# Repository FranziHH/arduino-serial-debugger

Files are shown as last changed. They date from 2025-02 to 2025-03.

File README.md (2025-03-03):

# ! Fork From arduino-serial-debugger
This is Forked From https://github.com/ma-ha/arduino-serial-debugger

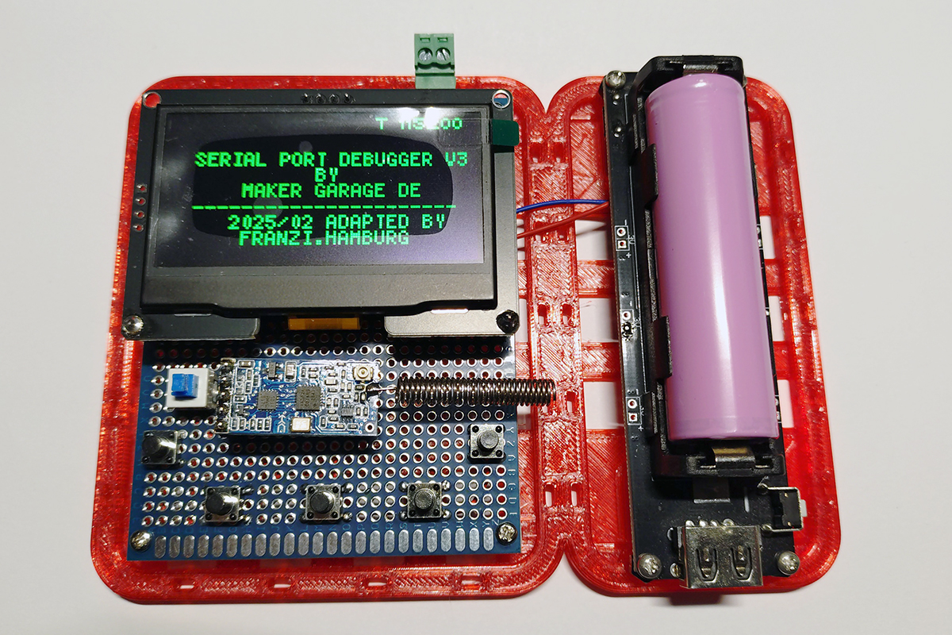
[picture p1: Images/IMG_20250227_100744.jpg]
Final Device with 18650 Battery
 
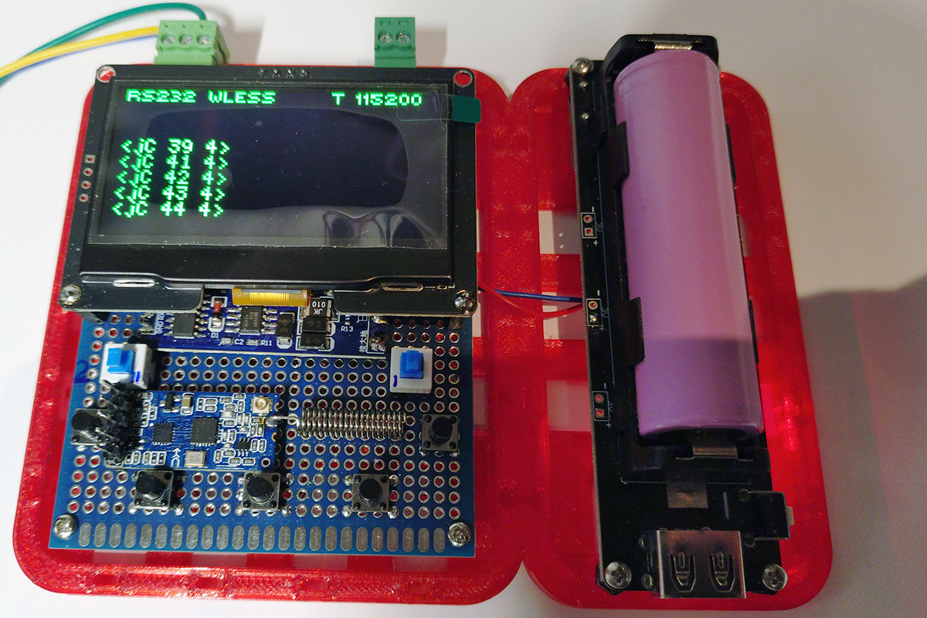
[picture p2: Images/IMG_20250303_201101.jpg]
Final Device Input HC12 wireless
 
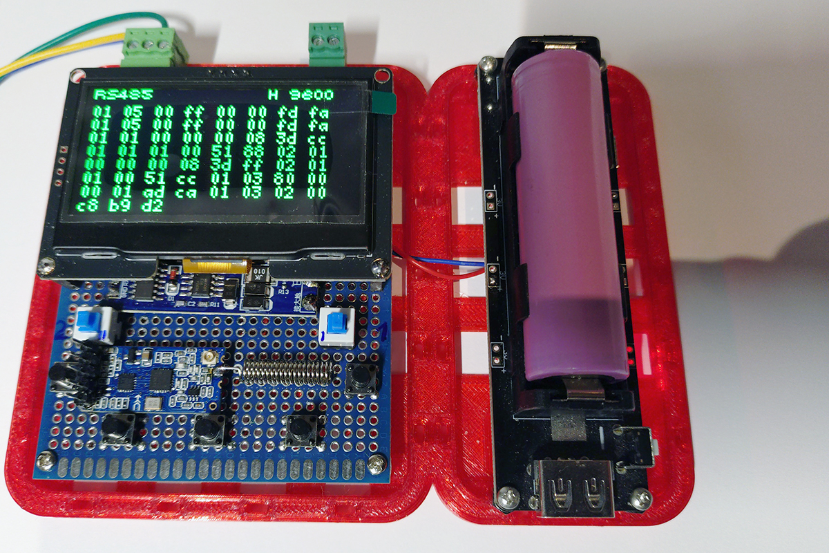
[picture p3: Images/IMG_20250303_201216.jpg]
Final Device Input RS485
 

# arduino-serial-debugger

Wire a Arduino Micro with a I2C OLED and 2 buttons, put it in a case 
... and you have a "Serial Port Debugger".

Push Buttons:
1. Toggle BAUD rate
2. Toggle display mode: HEX, BIN or TEXT

I've made a YouTube video about this project (German):
https://youtu.be/XUHYciV1GeM

# New
- Boards Arduino Nano and Uno added: Here debugging is disabled, there is only a hardware serial interface
- The display definition has been moved to config.h. Individual settings are possible here.

# Changes
- for easier use converted to vsCode
- third Button: Clear Screen added
- Added code for use with ESP32
- Error: interfaces must not be accessed in the interrupt
- ToDo: It is possible to add other boards for use

### ESP32-WROOM-32D

[ESP32 Pinout Reference](https://lastminuteengineers.com/esp32-pinout-reference/)
<br>

##### Connections
I2C Display, e.g.: 2,4-Zoll-OLED-Display 128x64 I2C SSD1309
- SCL - GPIO22
- SDA - GPIO21

Buttons - one PIN to GND
- Button Baud - GPIO19
- Button Mode - GPIO14
- Button Cls  - GPIO18

Serial Port (2)
- TX2 - GPIO17 (unused)
- RX2 - GPIO16
<br>

##### Additional
In addition, an HC-12 module was integrated
to monitor the wireless transmission
<br>

##### Images
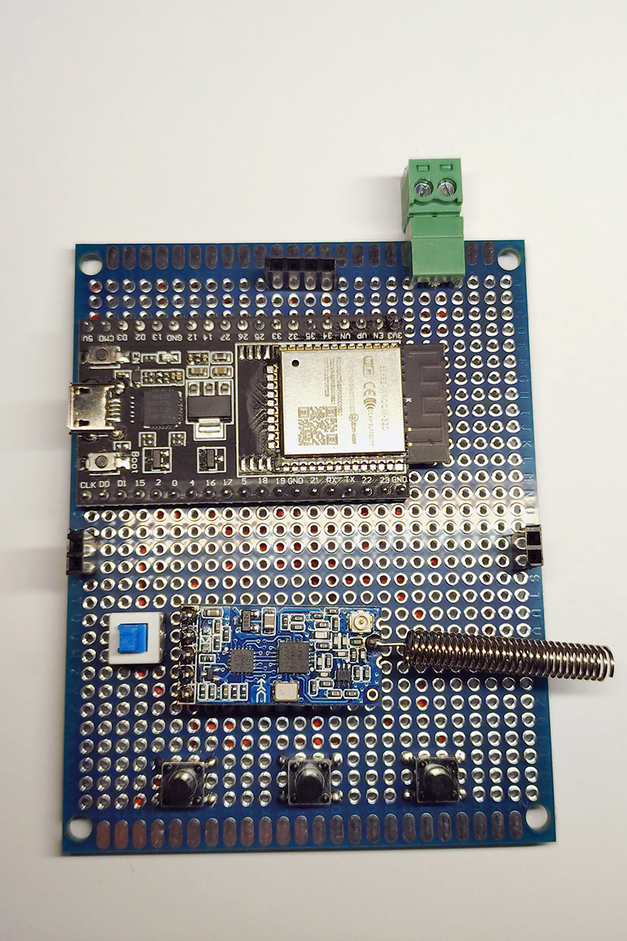
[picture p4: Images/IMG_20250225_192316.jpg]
PCB with ESP32
   
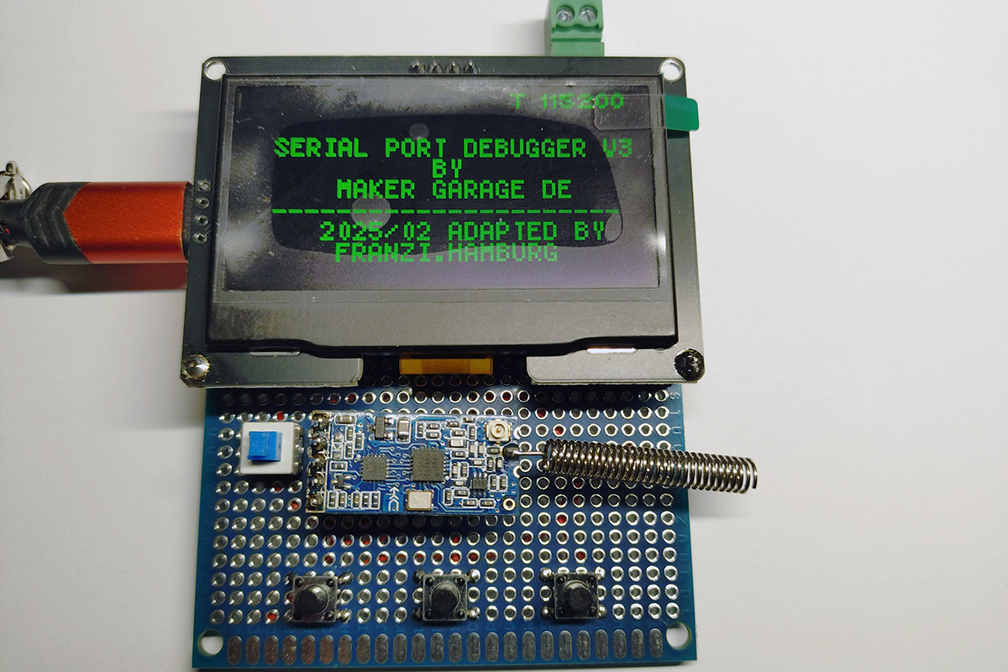
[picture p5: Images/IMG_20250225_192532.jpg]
Boot Screen
   
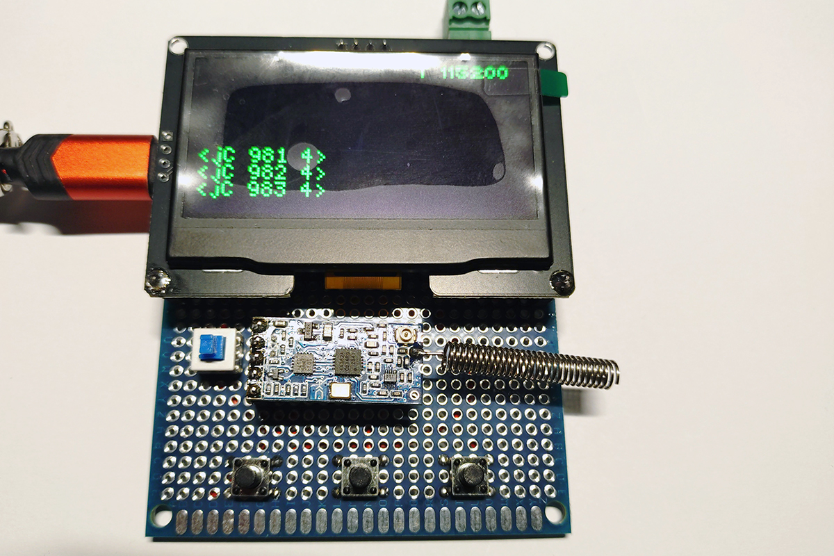
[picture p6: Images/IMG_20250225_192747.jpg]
Monitoring


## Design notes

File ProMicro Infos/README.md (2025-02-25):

# Upload ProMicro failes

https://learn.sparkfun.com/tutorials/pro-micro--fio-v3-hookup-guide/troubleshooting-and-faq

You need an Reset Button and must be fast ...

https://web.archive.org/web/20240706045800/https://forum.sparkfun.com/viewtopic.php?f=96&t=53770

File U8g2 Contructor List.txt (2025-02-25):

// Please UNCOMMENT one of the contructor lines below
// U8g2 Contructor List (Frame Buffer)
// The complete list is available here: https://github.com/olikraus/u8g2/wiki/u8g2setupcpp
// Please update the pin numbers according to your setup. Use U8X8_PIN_NONE if the reset pin is not connected
//U8G2_NULL u8g2(U8G2_R0);	// null device, a 8x8 pixel display which does nothing
//U8G2_SSD1306_128X64_NONAME_F_4W_SW_SPI u8g2(U8G2_R0, /* clock=*/ 13, /* data=*/ 11, /* cs=*/ 10, /* dc=*/ 9, /* reset=*/ 8);
//U8G2_SSD1306_128X64_NONAME_F_4W_HW_SPI u8g2(U8G2_R0, /* cs=*/ 12, /* dc=*/ 4, /* reset=*/ 6);	// Arduboy (Production, Kickstarter Edition)
//U8G2_SSD1306_128X64_NONAME_F_4W_HW_SPI u8g2(U8G2_R0, /* cs=*/ 10, /* dc=*/ 9, /* reset=*/ 8);
//U8G2_SSD1306_128X64_NONAME_F_3W_SW_SPI u8g2(U8G2_R0, /* clock=*/ 13, /* data=*/ 11, /* cs=*/ 10, /* reset=*/ 8);
//U8G2_SSD1306_128X64_NONAME_F_3W_HW_SPI u8g2(U8G2_R0, /* cs=*/ 10, /* reset=*/ 8);
//U8G2_SSD1306_128X64_NONAME_F_HW_I2C u8g2(U8G2_R0, /* reset=*/ U8X8_PIN_NONE);
//U8G2_SSD1306_128X64_ALT0_F_HW_I2C u8g2(U8G2_R0, /* reset=*/ U8X8_PIN_NONE);   // same as the NONAME variant, but may solve the "every 2nd line skipped" problem
//U8G2_SSD1306_128X64_NONAME_F_SW_I2C u8g2(U8G2_R0, /* clock=*/ 13, /* data=*/ 11, /* reset=*/ 8);
//U8G2_SSD1306_128X64_NONAME_F_SW_I2C u8g2(U8G2_R0, /* clock=*/ SCL, /* data=*/ SDA, /* reset=*/ U8X8_PIN_NONE);   // All Boards without Reset of the Display
//U8G2_SSD1306_128X64_NONAME_F_SW_I2C u8g2(U8G2_R0, /* clock=*/ 16, /* data=*/ 17, /* reset=*/ U8X8_PIN_NONE);   // ESP32 Thing, pure SW emulated I2C
//U8G2_SSD1306_128X64_NONAME_F_HW_I2C u8g2(U8G2_R0, /* reset=*/ U8X8_PIN_NONE, /* clock=*/ 16, /* data=*/ 17);   // ESP32 Thing, HW I2C with pin remapping
//U8G2_SSD1306_128X64_NONAME_F_6800 u8g2(U8G2_R0, 13, 11, 2, 3, 4, 5, 6, A4, /*enable=*/ 7, /*cs=*/ 10, /*dc=*/ 9, /*reset=*/ 8);
//U8G2_SSD1306_128X64_NONAME_F_8080 u8g2(U8G2_R0, 13, 11, 2, 3, 4, 5, 6, A4, /*enable=*/ 7, /*cs=*/ 10, /*dc=*/ 9, /*reset=*/ 8);
//U8G2_SSD1306_128X64_VCOMH0_F_4W_HW_SPI u8g2(U8G2_R0, /* cs=*/ 10, /* dc=*/ 9, /* reset=*/ 8);	// same as the NONAME variant, but maximizes setContrast() range
//U8G2_SSD1306_128X64_ALT0_F_4W_HW_SPI u8g2(U8G2_R0, /* cs=*/ 10, /* dc=*/ 9, /* reset=*/ 8);	// same as the NONAME variant, but may solve the "every 2nd line skipped" problem
//U8G2_SSD1306_102X64_EA_OLEDS102_F_4W_HW_SPI u8g2(U8G2_R0, /* cs=*/ 10, /* dc=*/ 9, /* reset=*/ 8);	// same as the NONAME variant, but may solve the "every 2nd line skipped" problem
//U8G2_SSD1312_128X64_NONAME_F_4W_SW_SPI u8g2(U8G2_R0, /* clock=*/ 13, /* data=*/ 11, /* cs=*/ 10, /* dc=*/ 9, /* reset=*/ 8);
//U8G2_SSD1312_128X64_NONAME_F_SW_I2C u8g2(U8G2_R0, /* clock=*/ SCL, /* data=*/ SDA, /* reset=*/ 8);
//U8G2_SSD1312_128X64_NONAME_F_HW_I2C u8g2(U8G2_R0, /* reset=*/ 8);
//U8G2_SSD1312_128X32_F_4W_SW_SPI u8g2(U8G2_R0, /* clock=*/ 13, /* data=*/ 11, /* cs=*/ 10, /* dc=*/ 9, /* reset=*/ 8);
//U8G2_SSD1312_128X32_F_SW_I2C u8g2(U8G2_R0, /* clock=*/ SCL, /* data=*/ SDA, /* reset=*/ 8);
//U8G2_SSD1312_128X32_F_HW_I2C u8g2(U8G2_R0, /* reset=*/ 8);
//U8G2_SSD1312_120X28_F_4W_SW_SPI u8g2(U8G2_R0, /* clock=*/ 13, /* data=*/ 11, /* cs=*/ 10, /* dc=*/ 9, /* reset=*/ 8);
//U8G2_SSD1312_120X28_F_SW_I2C u8g2(U8G2_R0, /* clock=*/ SCL, /* data=*/ SDA, /* reset=*/ 8);
//U8G2_SSD1312_120X28_F_HW_I2C u8g2(U8G2_R0, /* reset=*/ 8);
//U8G2_SH1106_128X64_NONAME_F_4W_HW_SPI u8g2(U8G2_R0, /* cs=*/ 10, /* dc=*/ 9, /* reset=*/ 8);
//U8G2_SH1106_128X64_NONAME_F_HW_I2C u8g2(U8G2_R0, /* reset=*/ U8X8_PIN_NONE);
//U8G2_SH1106_128X64_VCOMH0_F_4W_HW_SPI u8g2(U8G2_R0, /* cs=*/ 10, /* dc=*/ 9, /* reset=*/ 8);		// same as the NONAME variant, but maximizes setContrast() range
//U8G2_SH1106_128X64_WINSTAR_F_4W_HW_SPI u8g2(U8G2_R0, /* cs=*/ 10, /* dc=*/ 9, /* reset=*/ 8);		// same as the NONAME variant, but uses updated SH1106 init sequence
//U8G2_SH1106_128X32_VISIONOX_F_HW_I2C u8g2(U8G2_R0, /* reset=*/ U8X8_PIN_NONE); 
//U8G2_SH1106_128X32_VISIONOX_F_4W_HW_SPI u8g2(U8G2_R0, /* cs=*/ 10, /* dc=*/ 9, /* reset=*/ 8);
//U8G2_SH1106_72X40_WISE_F_4W_HW_SPI u8g2(U8G2_R0, /* cs=*/ 10, /* dc=*/ 9, /* reset=*/ 8);
//U8G2_SH1107_64X128_F_4W_HW_SPI u8g2(U8G2_R0, /* cs=*/ 10, /* dc=*/ 9, /* reset=*/ 8);
//U8G2_SH1107_128X128_F_4W_HW_SPI u8g2(U8G2_R0, /* cs=*/ 10, /* dc=*/ 9, /* reset=*/ 8);
//U8G2_SH1107_128X128_F_HW_I2C u8g2(U8G2_R0, /* reset=*/ 8);
//U8G2_SH1107_128X80_F_HW_I2C u8g2(U8G2_R0, /* reset=*/ 8);
//U8G2_SH1107_PIMORONI_128X128_F_HW_I2C u8g2(U8G2_R0, /* reset=*/ 8);
//U8G2_SH1107_SEEED_128X128_F_SW_I2C u8g2(U8G2_R0, /* clock=*/ SCL, /* data=*/ SDA, /* reset=*/ U8X8_PIN_NONE);
//U8G2_SH1107_SEEED_128X128_F_HW_I2C u8g2(U8G2_R0, /* reset=*/ U8X8_PIN_NONE);
//U8G2_SH1107_SEEED_96X96_F_4W_HW_SPI u8g2(U8G2_R0, /* cs=*/ 10, /* dc=*/ 9, /* reset=*/ 8);#
//U8G2_SH1107_HJR_OEL1M0201_96X96_F_SW_I2C u8g2(U8G2_R0, /* clock=*/ 2, /* data=*/ 0, /* reset=*/ U8X8_PIN_NONE); 
//U8G2_SH1107_TK078F288_80X128_F_4W_HW_SPI u8g2(U8G2_R0, /* cs=*/ 15, /* dc=*/ 0, /* reset=*/ U8X8_PIN_NONE);
//U8G2_SH1108_128X160_F_4W_HW_SPI u8g2(U8G2_R0, /* cs=*/ 10, /* dc=*/ 9, /* reset=*/ 8);
//U8G2_CH1120_128X160_F_4W_HW_SPI u8g2(U8G2_R0, /* cs=*/ 10, /* dc=*/ 9, /* reset=*/ 8);
//U8G2_SH1108_160X160_F_4W_HW_SPI u8g2(U8G2_R0, /* cs=*/ 10, /* dc=*/ 9, /* reset=*/ 8);
//U8G2_SH1122_256X64_F_4W_HW_SPI u8g2(U8G2_R0, /* cs=*/ 10, /* dc=*/ 9, /* reset=*/ 8);				// Enable U8G2_16BIT in u8g2.h
//U8G2_SH1122_256X64_F_4W_SW_SPI u8g2(U8G2_R0, /* clock=*/ 13, /* data=*/ 11, /* cs=*/ 10, /* dc=*/ 9, /* reset=*/ 8);        // Enable U8G2_16BIT in u8g2.h
//U8G2_SSD1306_128X32_UNIVISION_F_SW_I2C u8g2(U8G2_R0, /* clock=*/ 21, /* data=*/ 20, /* reset=*/ U8X8_PIN_NONE);   // Adafruit Feather M0 Basic Proto + FeatherWing OLED
//U8G2_SSD1306_128X32_UNIVISION_F_SW_I2C u8g2(U8G2_R0, /* clock=*/ SCL, /* data=*/ SDA, /* reset=*/ U8X8_PIN_NONE);   // Adafruit Feather ESP8266/32u4 Boards + FeatherWing OLED
//U8G2_SSD1306_128X32_UNIVISION_F_HW_I2C u8g2(U8G2_R0, /* reset=*/ U8X8_PIN_NONE);  // Adafruit ESP8266/32u4/ARM Boards + FeatherWing OLED
//U8G2_SSD1306_128X32_UNIVISION_F_HW_I2C u8g2(U8G2_R0, /* reset=*/ U8X8_PIN_NONE, /* clock=*/ SCL, /* data=*/ SDA);   // pin remapping with ESP8266 HW I2C
//U8G2_SSD1306_128X32_WINSTAR_F_HW_I2C u8g2(U8G2_R0, /* reset=*/ U8X8_PIN_NONE, /* clock=*/ SCL, /* data=*/ SDA);   // pin remapping with ESP8266 HW I2C
//U8G2_SSD1306_64X48_ER_F_HW_I2C u8g2(U8G2_R0, /* reset=*/ U8X8_PIN_NONE);   // EastRising 0.66" OLED breakout board, Uno: A4=SDA, A5=SCL, 5V powered
//U8G2_SSD1306_48X64_WINSTAR_F_HW_I2C u8g2(U8G2_R0, /* reset=*/ U8X8_PIN_NONE);   
//U8G2_SSD1306_64X32_NONAME_F_HW_I2C u8g2(U8G2_R0, /* reset=*/ U8X8_PIN_NONE); 
//U8G2_SSD1306_64X32_1F_F_HW_I2C u8g2(U8G2_R0, /* reset=*/ U8X8_PIN_NONE); 
//U8G2_SSD1306_96X16_ER_F_HW_I2C u8g2(U8G2_R0, /* reset=*/ U8X8_PIN_NONE);   // EastRising 0.69" OLED
//U8G2_SSD1306_72X40_ER_F_HW_I2C u8g2(U8G2_R0, /* reset=*/ U8X8_PIN_NONE);   // EastRising 0.42" OLED
//U8G2_SSD1306_96X40_F_HW_I2C u8g2(U8G2_R0, /* reset=*/ U8X8_PIN_NONE);
//U8G2_SSD1306_96X39_F_HW_I2C u8g2(U8G2_R0, /* reset=*/ U8X8_PIN_NONE);
//U8G2_SSD1320_160X132_F_4W_SW_SPI u8g2(U8G2_R0, /* clock=*/ 13, /* data=*/ 11, /* cs=*/ 10, /* dc=*/ 9, /* reset=*/ 8);  
//U8G2_SSD1320_160X132_F_4W_HW_SPI u8g2(U8G2_R0, /* cs=*/ 10, /* dc=*/ 9, /* reset=*/ 8); 	
//U8G2_SSD1320_160X80_F_4W_SW_SPI u8g2(U8G2_R0, /* clock=*/ 13, /* data=*/ 11, /* cs=*/ 10, /* dc=*/ 9, /* reset=*/ 8);  
//U8G2_SSD1320_160X80_F_4W_HW_SPI u8g2(U8G2_R0, /* cs=*/ 10, /* dc=*/ 9, /* reset=*/ 8); 	
//U8G2_SSD1322_240X128_F_4W_SW_SPI u8g2(U8G2_R0, /* clock=*/ 13, /* data=*/ 11, /* cs=*/ 10, /* dc=*/ 9, /* reset=*/ 8);	// Enable U8G2_16BIT in u8g2.h
//U8G2_SSD1322_TOPWIN_240X128_F_4W_SW_SPI u8g2(U8G2_R0, /* clock=*/ 13, /* data=*/ 11, /* cs=*/ 10, /* dc=*/ 9, /* reset=*/ 8);	// Enable U8G2_16BIT in u8g2.h
//U8G2_SSD1322_NHD_256X64_F_4W_SW_SPI u8g2(U8G2_R0, /* clock=*/ 13, /* data=*/ 11, /* cs=*/ 10, /* dc=*/ 9, /* reset=*/ 8);	// Enable U8G2_16BIT in u8g2.h
//U8G2_SSD1322_NHD_256X64_F_4W_HW_SPI u8g2(U8G2_R0, /* cs=*/ 10, /* dc=*/ 9, /* reset=*/ 8);	// Enable U8G2_16BIT in u8g2.h
//U8G2_SSD1322_ZJY_256X64_F_4W_SW_SPI u8g2(U8G2_R0, /* clock=*/ 13, /* data=*/ 11, /* cs=*/ 10, /* dc=*/ 9, /* reset=*/ 8);	// Enable U8G2_16BIT in u8g2.h
//U8G2_SSD1322_ZJY_256X64_F_4W_HW_SPI u8g2(U8G2_R0, /* cs=*/ 10, /* dc=*/ 9, /* reset=*/ 8);	// Enable U8G2_16BIT in u8g2.h
//U8G2_SSD1362_256X64_F_4W_SW_SPI u8g2(U8G2_R0, /* clock=*/ 13, /* data=*/ 11, /* cs=*/ 10, /* dc=*/ 9, /* reset=*/ 8);	// Enable U8G2_16BIT in u8g2.h
//U8G2_SSD1362_256X64_F_4W_HW_SPI u8g2(U8G2_R0, /* cs=*/ 10, /* dc=*/ 9, /* reset=*/ 8);	// Enable U8G2_16BIT in u8g2.h
//U8G2_SSD1362_206X36_F_4W_SW_SPI u8g2(U8G2_R0, /* clock=*/ 13, /* data=*/ 11, /* cs=*/ 10, /* dc=*/ 9, /* reset=*/ 8);
//U8G2_SSD1362_206X36_F_4W_HW_SPI u8g2(U8G2_R0, /* cs=*/ 10, /* dc=*/ 9, /* reset=*/ 8);
//U8G2_SSD1363_256X128_F_4W_SW_SPI u8g2(U8G2_R0, /* clock=*/ 13, /* data=*/ 11, /* cs=*/ 10, /* dc=*/ 9, /* reset=*/ 8);	// Enable U8G2_16BIT in u8g2.h
//U8G2_SSD1363_256X128_F_4W_HW_SPI u8g2(U8G2_R0, /* cs=*/ 10, /* dc=*/ 9, /* reset=*/ 8);	// Enable U8G2_16BIT in u8g2.h
//U8G2_SSD1322_NHD_128X64_F_4W_SW_SPI u8g2(U8G2_R0, /* clock=*/ 13, /* data=*/ 11, /* cs=*/ 10, /* dc=*/ 9, /* reset=*/ 8);
//U8G2_SSD1322_NHD_128X64_F_4W_HW_SPI u8g2(U8G2_R0, /* cs=*/ 10, /* dc=*/ 9, /* reset=*/ 8);
//U8G2_SSD1325_NHD_128X64_F_4W_SW_SPI u8g2(U8G2_R0, /* clock=*/ 13, /* data=*/ 11, /* cs=*/ 10, /* dc=*/ 9, /* reset=*/ 8); 
//U8G2_SSD1325_NHD_128X64_F_4W_HW_SPI u8g2(U8G2_R0, /* cs=*/ 10, /* dc=*/ 9, /* reset=*/ 8);	
//U8G2_SSD0323_OS128064_F_4W_SW_SPI u8g2(U8G2_R0, /* clock=*/ 13, /* data=*/ 11, /* cs=*/ 10, /* dc=*/ 9, /* reset=*/ 8); 
//U8G2_SSD0323_OS128064_F_4W_HW_SPI u8g2(U8G2_R0, /* cs=*/ 10, /* dc=*/ 9, /* reset=*/ 8);	
//U8G2_SSD1326_ER_256X32_1_4W_SW_SPI u8g2(U8G2_R0, /* clock=*/ 13, /* data=*/ 11, /* cs=*/ 10, /* dc=*/ 9, /* reset=*/ 8);         // experimental driver for ER-OLED018-1
//U8G2_SSD1327_SEEED_96X96_F_SW_I2C u8g2(U8G2_R0, /* clock=*/ SCL, /* data=*/ SDA, /* reset=*/ U8X8_PIN_NONE);	// Seeedstudio Grove OLED 96x96
//U8G2_SSD1327_SEEED_96X96_F_HW_I2C u8g2(U8G2_R0, /* reset=*/ U8X8_PIN_NONE);	// Seeedstudio Grove OLED 96x96
//U8G2_SSD1327_EA_W128128_F_4W_SW_SPI u8g2(U8G2_R0, /* clock=*/ 13, /* data=*/ 11, /* cs=*/ 10, /* dc=*/ 9, /* reset=*/ 8);
//U8G2_SSD1327_EA_W128128_F_4W_HW_SPI u8g2(U8G2_R0, /* cs=*/ 10, /* dc=*/ 9, /* reset=*/ 8);
//U8G2_SSD1327_EA_W128128_F_SW_I2C u8g2(U8G2_R0, /* clock=*/ 5, /* data=*/ 4, /* reset=*/ U8X8_PIN_NONE);
//U8G2_SSD1327_EA_W128128_F_HW_I2C u8g2(U8G2_R0, /* reset=*/ U8X8_PIN_NONE);  /* Uno: A4=SDA, A5=SCL, add "u8g2.setBusClock(400000);" into setup() for speedup if possible */
//U8G2_SSD1327_MIDAS_128X128_F_4W_SW_SPI u8g2(U8G2_R0, /* clock=*/ 13, /* data=*/ 11, /* cs=*/ 10, /* dc=*/ 9, /* reset=*/ 8);
//U8G2_SSD1327_MIDAS_128X128_F_4W_HW_SPI u8g2(U8G2_R0, /* cs=*/ 10, /* dc=*/ 9, /* reset=*/ 8);
//U8G2_SSD1327_MIDAS_128X128_F_HW_I2C u8g2(U8G2_R0, /* reset=*/ U8X8_PIN_NONE); /* Uno: A4=SDA, A5=SCL, add "u8g2.setBusClock(400000);" into setup() for speedup if possible */
//U8G2_SSD1327_ZJY_128X128_F_4W_SW_SPI u8g2(U8G2_R0, /* clock=*/ 13, /* data=*/ 11, /* cs=*/ 10, /* dc=*/ 9, /* reset=*/ 8);
//U8G2_SSD1327_ZJY_128X128_F_4W_HW_SPI u8g2(U8G2_R0, /* cs=*/ 10, /* dc=*/ 9, /* reset=*/ 8);
//U8G2_SSD1327_ZJY_128X128_F_HW_I2C u8g2(U8G2_R0, /* reset=*/ U8X8_PIN_NONE); /* Uno: A4=SDA, A5=SCL, add "u8g2.setBusClock(400000);" into setup() for speedup if possible */
//U8G2_SSD1327_WS_128X128_F_4W_SW_SPI u8g2(U8G2_R0, /* clock=*/ 13, /* data=*/ 11, /* cs=*/ 10, /* dc=*/ 9, /* reset=*/ 8);
//U8G2_SSD1327_WS_128X128_F_4W_HW_SPI u8g2(U8G2_R0, /* cs=*/ 10, /* dc=*/ 9, /* reset=*/ 8);
//U8G2_SSD1327_VISIONOX_128X96_F_4W_SW_SPI u8g2(U8G2_R0, /* clock=*/ 13, /* data=*/ 11, /* cs=*/ 10, /* dc=*/ 9, /* reset=*/ 8);
//U8G2_SSD1327_VISIONOX_128X96_F_4W_HW_SPI u8g2(U8G2_R0, /* cs=*/ 10, /* dc=*/ 9, /* reset=*/ 8);
//U8G2_SSD1329_128X96_NONAME_F_4W_SW_SPI u8g2(U8G2_R0, /* clock=*/ 13, /* data=*/ 11, /* cs=*/ 10, /* dc=*/ 9, /* reset=*/ 8);
//U8G2_SSD1329_128X96_NONAME_F_4W_HW_SPI u8g2(U8G2_R0, /* cs=*/ 10, /* dc=*/ 9, /* reset=*/ 8);
//U8G2_SSD1329_96X96_NONAME_F_4W_SW_SPI u8g2(U8G2_R0, /* clock=*/ 13, /* data=*/ 11, /* cs=*/ 10, /* dc=*/ 9, /* reset=*/ 8);
//U8G2_SSD1329_96X96_NONAME_F_4W_HW_SPI u8g2(U8G2_R0, /* cs=*/ 10, /* dc=*/ 9, /* reset=*/ 8);
//U8G2_SSD1329_96X96_NONAME_F_4W_HW_SPI u8g2(U8G2_R0, /* cs=*/ A4, /* dc=*/ A2, /* reset=*/ U8X8_PIN_NONE); //  Adafruit Feather 32u4 Basic Proto
//U8G2_SSD1305_128X32_NONAME_F_4W_SW_SPI u8g2(U8G2_R0, /* clock=*/ 13, /* data=*/ 11, /* cs=*/ 10, /* dc=*/ 9, /* reset=*/ 8);
//U8G2_SSD1305_128X32_NONAME_F_4W_HW_SPI u8g2(U8G2_R0, /* cs=*/ 10, /* dc=*/ 9, /* reset=*/ 8);
//U8G2_SSD1305_128X32_ADAFRUIT_F_4W_SW_SPI u8g2(U8G2_R0, /* clock=*/ 13, /* data=*/ 11, /* cs=*/ 10, /* dc=*/ 9, /* reset=*/ 8);
//U8G2_SSD1305_128X32_ADAFRUIT_F_4W_HW_SPI u8g2(U8G2_R0, /* cs=*/ 10, /* dc=*/ 9, /* reset=*/ 8);
//U8G2_SSD1305_128X64_ADAFRUIT_F_4W_SW_SPI u8g2(U8G2_R0, /* clock=*/ 13, /* data=*/ 11, /* cs=*/ 10, /* dc=*/ 9, /* reset=*/ 8);
//U8G2_SSD1305_128X64_ADAFRUIT_F_4W_HW_SPI u8g2(U8G2_R0, /* cs=*/ 10, /* dc=*/ 9, /* reset=*/ 8);
//U8G2_SSD1305_128X64_RAYSTAR_F_4W_SW_SPI u8g2(U8G2_R0, /* clock=*/ 13, /* data=*/ 11, /* cs=*/ 10, /* dc=*/ 9, /* reset=*/ 8);
//U8G2_SSD1305_128X64_RAYSTAR_F_4W_HW_SPI u8g2(U8G2_R0, /* cs=*/ 10, /* dc=*/ 9, /* reset=*/ 8);
//U8G2_SSD1309_128X64_NONAME0_F_4W_SW_SPI u8g2(U8G2_R0, /* clock=*/ 13, /* data=*/ 11, /* cs=*/ 10, /* dc=*/ 9, /* reset=*/ 8);  
//U8G2_SSD1309_128X64_NONAME0_F_4W_HW_SPI u8g2(U8G2_R0, /* cs=*/ 10, /* dc=*/ 9, /* reset=*/ 8);  
//U8G2_SSD1309_128X64_NONAME2_F_4W_SW_SPI u8g2(U8G2_R0, /* clock=*/ 13, /* data=*/ 11, /* cs=*/ 10, /* dc=*/ 9, /* reset=*/ 8);  
//U8G2_SSD1309_128X64_NONAME2_F_4W_HW_SPI u8g2(U8G2_R0, /* cs=*/ 10, /* dc=*/ 9, /* reset=*/ 8);  
//U8G2_SSD1316_128X32_F_4W_SW_SPI u8g2(U8G2_R0, /* clock=*/ 13, /* data=*/ 11, /* cs=*/ 10, /* dc=*/ 9, /* reset=*/ 8);  
//U8G2_SSD1316_128X32_F_4W_HW_SPI u8g2(U8G2_R0, /* cs=*/ 10, /* dc=*/ 9, /* reset=*/ 8); 	
//U8G2_SSD1316_96X32_F_4W_SW_SPI u8g2(U8G2_R0, /* clock=*/ 13, /* data=*/ 11, /* cs=*/ 10, /* dc=*/ 9, /* reset=*/ 8);  
//U8G2_SSD1316_96X32_F_4W_HW_SPI u8g2(U8G2_R0, /* cs=*/ 10, /* dc=*/ 9, /* reset=*/ 8); 	
//U8G2_SSD1317_96X96_F_4W_SW_SPI u8g2(U8G2_R0, /* clock=*/ 13, /* data=*/ 11, /* cs=*/ 10, /* dc=*/ 9, /* reset=*/ 8);  // not tested, not confirmed
//U8G2_SSD1317_96X96_F_4W_HW_SPI u8g2(U8G2_R0, /* cs=*/ 10, /* dc=*/ 9, /* reset=*/ 8); 	// not tested, not confirmed
//U8G2_SSD1318_128X96_F_4W_SW_SPI u8g2(U8G2_R0, /* clock=*/ 13, /* data=*/ 11, /* cs=*/ 10, /* dc=*/ 9, /* reset=*/ 8);  
//U8G2_SSD1318_128X96_F_4W_HW_SPI u8g2(U8G2_R0, /* cs=*/ 10, /* dc=*/ 9, /* reset=*/ 8); 
//U8G2_LD7032_60X32_F_4W_SW_SPI u8g2(U8G2_R0, /* clock=*/ 11, /* data=*/ 12, /* cs=*/ 9, /* dc=*/ 10, /* reset=*/ 8);	// SW SPI Nano Board
//U8G2_LD7032_60X32_F_SW_I2C u8g2(U8G2_R0, /* clock=*/ 11, /* data=*/ 12, /* reset=*/ U8X8_PIN_NONE);	// NOT TESTED!
//U8G2_LD7032_60X32_ALT_F_4W_SW_SPI u8g2(U8G2_R0, /* clock=*/ 11, /* data=*/ 12, /* cs=*/ 9, /* dc=*/ 10, /* reset=*/ 8);	// SW SPI Nano Board
//U8G2_LD7032_60X32_ALT_F_SW_I2C u8g2(U8G2_R0, /* clock=*/ 11, /* data=*/ 12, /* reset=*/ U8X8_PIN_NONE);	// NOT TESTED!
//U8G2_LD7032_128X36_F_4W_SW_SPI u8g2(U8G2_R0, /* clock=*/ 11, /* data=*/ 12, /* cs=*/ 9, /* dc=*/ 10, /* reset=*/ 8);	// SW SPI Nano Board
//U8G2_LD7032_128X36_F_SW_I2C u8g2(U8G2_R0, /* clock=*/ 11, /* data=*/ 12, /* reset=*/ U8X8_PIN_NONE);	// NOT TESTED!
//U8G2_UC1701_EA_DOGS102_F_4W_SW_SPI u8g2(U8G2_R0, /* clock=*/ 13, /* data=*/ 11, /* cs=*/ 10, /* dc=*/ 9, /* reset=*/ 8);
//U8G2_UC1701_EA_DOGS102_F_4W_HW_SPI u8g2(U8G2_R0, /* cs=*/ 10, /* dc=*/ 9, /* reset=*/ 8);
//U8G2_PCD8544_84X48_F_4W_SW_SPI u8g2(U8G2_R0, /* clock=*/ 13, /* data=*/ 11, /* cs=*/ 10, /* dc=*/ 9, /* reset=*/ 8);  // Nokia 5110 Display
//U8G2_PCD8544_84X48_F_4W_HW_SPI u8g2(U8G2_R0, /* cs=*/ 10, /* dc=*/ 9, /* reset=*/ 8); 		// Nokia 5110 Display
//U8G2_PCF8812_96X65_F_4W_SW_SPI u8g2(U8G2_R0, /* clock=*/ 13, /* data=*/ 11, /* cs=*/ 10, /* dc=*/ 9, /* reset=*/ 8);	// Could be also PCF8814
//U8G2_PCF8812_96X65_F_4W_HW_SPI u8g2(U8G2_R0, /* cs=*/ 10, /* dc=*/ 9, /* reset=*/ 8);						// Could be also PCF8814
//U8G2_PCF8812_101X64_F_4W_SW_SPI u8g2(U8G2_R0, /* clock=*/ 13, /* data=*/ 11, /* cs=*/ 10, /* dc=*/ 9, /* reset=*/ 8);	// Could be also PCF8814
//U8G2_PCF8812_101X64_F_4W_HW_SPI u8g2(U8G2_R0, /* cs=*/ 10, /* dc=*/ 9, /* reset=*/ 8);						// Could be also PCF8814
//U8G2_HX1230_96X68_F_3W_SW_SPI u8g2(U8G2_R0, /* clock=*/ 13, /* data=*/ 11, /* cs=*/ 10, /* reset=*/ 8);
//U8G2_HX1230_96X68_F_4W_SW_SPI u8g2(U8G2_R0, /* clock=*/ 13, /* data=*/ 11, /* cs=*/ 10, /* dc=*/ 9, /* reset=*/ 8);
//U8G2_KS0108_128X64_F u8g2(U8G2_R0, 8, 9, 10, 11, 4, 5, 6, 7, /*enable=*/ 18, /*dc=*/ 17, /*cs0=*/ 14, /*cs1=*/ 15, /*cs2=*/ U8X8_PIN_NONE, /* reset=*/  U8X8_PIN_NONE); 	// Set R/W to low!
//U8G2_KS0108_ERM19264_F u8g2(U8G2_R0, 8, 9, 10, 11, 4, 5, 6, 7, /*enable=*/ 18, /*dc=*/ 17, /*cs0=*/ 14, /*cs1=*/ 15, /*cs2=*/ 16, /* reset=*/  U8X8_PIN_NONE); 	// Set R/W to low!
//U8G2_HD44102_100X64_F u8g2(U8G2_R0, 4, 5, 6, 7, 8, 9, 10, 11, /*enable=*/ 2, /*dc=*/ 3, /*cs0=*/ A0, /*cs1=*/ A1, /*cs2=*/ A2, /* reset=*/  U8X8_PIN_NONE); 	// Set R/W to low!
//U8G2_T7932_150X32_F u8g2(U8G2_R0, 4, 5, 6, 7, 8, 9, 10, 11, /*enable=*/ 2, /*dc=*/ 3, /*cs0=*/ A0, /*cs1=*/ A1, /*cs2=*/ A2, /* reset=*/  U8X8_PIN_NONE); 	// Set R/W to low!
//U8G2_ST7920_256X32_F_8080 u8g2(U8G2_R0, 8, 9, 10, 11, 4, 5, 6, 7, /*enable=*/ 18, /*cs=*/ U8X8_PIN_NONE, /*dc=*/ 17, /*reset=*/ U8X8_PIN_NONE);
//U8G2_ST7920_256X32_F_SW_SPI u8g2(U8G2_R0, /* clock=*/ 18 /* A4 */ , /* data=*/ 16 /* A2 */, /* CS=*/ 17 /* A3 */, /* reset=*/ U8X8_PIN_NONE);
//U8G2_ST7920_192X32_F_8080 u8g2(U8G2_R0, 8, 9, 10, 11, 4, 5, 6, 7, /*enable=*/ 18, /*cs=*/ U8X8_PIN_NONE, /*dc=*/ 17, /*reset=*/ U8X8_PIN_NONE);
//U8G2_ST7920_192X32_F_SW_SPI u8g2(U8G2_R0, /* clock=*/ 18 /* A4 */ , /* data=*/ 16 /* A2 */, /* CS=*/ 17 /* A3 */, /* reset=*/ U8X8_PIN_NONE);
//U8G2_ST7920_128X32_F_8080 u8g2(U8G2_R0, 8, 9, 10, 11, 4, 5, 6, 7, /*enable=*/ 18, /*cs=*/ U8X8_PIN_NONE, /*dc=*/ 17, /*reset=*/ U8X8_PIN_NONE);
//U8G2_ST7920_128X32_F_SW_SPI u8g2(U8G2_R0, /* clock=*/ 18 /* A4 */ , /* data=*/ 16 /* A2 */, /* CS=*/ 17 /* A3 */, /* reset=*/ U8X8_PIN_NONE);
//U8G2_ST7920_144X32_F_8080 u8g2(U8G2_R0, 8, 9, 10, 11, 4, 5, 6, 7, /*enable=*/ 18, /*cs=*/ U8X8_PIN_NONE, /*dc=*/ 17, /*reset=*/ U8X8_PIN_NONE);
//U8G2_ST7920_144X32_F_SW_SPI u8g2(U8G2_R0, /* clock=*/ 18 /* A4 */ , /* data=*/ 16 /* A2 */, /* CS=*/ 17 /* A3 */, /* reset=*/ U8X8_PIN_NONE);
//U8G2_ST7920_160X32_F_8080 u8g2(U8G2_R0, 8, 9, 10, 11, 4, 5, 6, 7, /*enable=*/ 18, /*cs=*/ U8X8_PIN_NONE, /*dc=*/ 17, /*reset=*/ U8X8_PIN_NONE);
//U8G2_ST7920_160X32_F_SW_SPI u8g2(U8G2_R0, /* clock=*/ 18 /* A4 */ , /* data=*/ 16 /* A2 */, /* CS=*/ 17 /* A3 */, /* reset=*/ U8X8_PIN_NONE);
//U8G2_ST7920_128X64_F_8080 u8g2(U8G2_R0, 8, 9, 10, 11, 4, 5, 6, 7, /*enable=*/ 18 /* A4 */, /*cs=*/ U8X8_PIN_NONE, /*dc/rs=*/ 17 /* A3 */, /*reset=*/ 15 /* A1 */);	// Remember to set R/W to 0 
//U8G2_ST7920_128X64_F_SW_SPI u8g2(U8G2_R0, /* clock=*/ 18 /* A4 */ , /* data=*/ 16 /* A2 */, /* CS=*/ 17 /* A3 */, /* reset=*/ U8X8_PIN_NONE);
//U8G2_ST7920_128X64_F_SW_SPI u8g2(U8G2_R0, /* clock=*/ 13, /* data=*/ 11, /* CS=*/ 10, /* reset=*/ 8);
//U8G2_ST7920_128X64_F_SW_SPI u8g2(U8G2_R0, /* clock=*/ 14, /* data=*/ 13, /* CS=*/ 15, /* reset=*/ 16); // Feather HUZZAH ESP8266, E=clock=14, RW=data=13, RS=CS
//U8G2_ST7920_128X64_F_HW_SPI u8g2(U8G2_R0, /* CS=*/ 10, /* reset=*/ 8);
//U8G2_ST7920_128X64_F_HW_SPI u8g2(U8G2_R0, /* CS=*/ 15, /* reset=*/ 16); // Feather HUZZAH ESP8266, E=clock=14, RW=data=13, RS=CS
//U8G2_ST7528_ERC16064_F_4W_SW_SPI u8g2(U8G2_R0, /* clock=*/ 13, /* data=*/ 11, /* cs=*/ 10, /* dc=*/ 9, /* reset=*/ 8);
//U8G2_ST7528_ERC16064_F_4W_HW_SPI u8g2(U8G2_R0, /* cs=*/ 10, /* dc=*/ 9, /* reset=*/ 8);
//U8G2_ST7539_192X64_F_4W_SW_SPI u8g2(U8G2_R0, /* clock=*/ 13, /* data=*/ 11, /* cs=*/ 10, /* dc=*/ 9, /* reset=*/ 8);
//U8G2_ST7539_192X64_F_4W_HW_SPI u8g2(U8G2_R0, /* cs=*/ 10, /* dc=*/ 9, /* reset=*/ 8);
//U8G2_ST7565_EA_DOGM128_F_4W_SW_SPI u8g2(U8G2_R0, /* clock=*/ 13, /* data=*/ 11, /* cs=*/ 10, /* dc=*/ 9, /* reset=*/ 8);
//U8G2_ST7565_EA_DOGM128_F_4W_HW_SPI u8g2(U8G2_R0, /* cs=*/ 10, /* dc=*/ 9, /* reset=*/ 8);
//U8G2_ST7565_64128N_F_4W_SW_SPI u8g2(U8G2_R0, /* clock=*/ 13, /* data=*/ 11, /* cs=*/ 10, /* dc=*/ 9, /* reset=*/ 8);
//U8G2_ST7565_64128N_F_4W_HW_SPI u8g2(U8G2_R0, /* cs=*/ 10, /* dc=*/ 9, /* reset=*/ 8);
//U8G2_ST7565_EA_DOGM132_F_4W_SW_SPI u8g2(U8G2_R0, /* clock=*/ 13, /* data=*/ 11, /* cs=*/ 10, /* dc=*/ 9, /* reset=*/ U8X8_PIN_NONE);	// DOGM132 Shield
//U8G2_ST7565_EA_DOGM132_F_4W_HW_SPI u8g2(U8G2_R0, /* cs=*/ 10, /* dc=*/ 9, /* reset=*/ U8X8_PIN_NONE);	// DOGM132 Shield
//U8G2_ST7565_ZOLEN_128X64_F_4W_SW_SPI u8g2(U8G2_R0, /* clock=*/ 13, /* data=*/ 11, /* cs=*/ 10, /* dc=*/ 9, /* reset=*/ 8);
//U8G2_ST7565_ZOLEN_128X64_F_4W_HW_SPI u8g2(U8G2_R0, /* cs=*/ 10, /* dc=*/ 9, /* reset=*/ 8);
//U8G2_ST7565_LM6059_F_4W_SW_SPI u8g2(U8G2_R0, /* clock=*/ 13, /* data=*/ 11, /* cs=*/ 10, /* dc=*/ 9, /* reset=*/ 8);		// Adafruit ST7565 GLCD
//U8G2_ST7565_LM6059_F_4W_HW_SPI u8g2(U8G2_R0, /* cs=*/ 10, /* dc=*/ 9, /* reset=*/ 8);		// Adafruit ST7565 GLCD
//U8G2_ST7565_KS0713_F_4W_SW_SPI u8g2(U8G2_R0, /* clock=*/ 13, /* data=*/ 11, /* cs=*/ 10, /* dc=*/ 9, /* reset=*/ 8);		// KS0713 controller
//U8G2_ST7565_KS0713_F_4W_HW_SPI u8g2(U8G2_R0, /* cs=*/ 10, /* dc=*/ 9, /* reset=*/ 8);			// KS0713 controller
//U8G2_ST7565_LX12864_F_4W_SW_SPI u8g2(U8G2_R0, /* clock=*/ 13, /* data=*/ 11, /* cs=*/ 10, /* dc=*/ 9, /* reset=*/ 8);
//U8G2_ST7565_LX12864_F_4W_HW_SPI u8g2(U8G2_R0, /* cs=*/ 10, /* dc=*/ 9, /* reset=*/ 8);
//U8G2_ST7565_ERC12864_F_4W_SW_SPI u8g2(U8G2_R0, /* clock=*/ 13, /* data=*/ 11, /* cs=*/ 10, /* dc=*/ 9, /* reset=*/ 8);
//U8G2_ST7565_ERC12864_F_4W_HW_SPI u8g2(U8G2_R0, /* cs=*/ 10, /* dc=*/ 9, /* reset=*/ 8);
//U8G2_ST7565_ERC12864_ALT_F_4W_SW_SPI u8g2(U8G2_R0, /* clock=*/ 13, /* data=*/ 11, /* cs=*/ 10, /* dc=*/ 9, /* reset=*/ 8); // contrast improved version for ERC12864
//U8G2_ST7565_ERC12864_ALT_F_4W_HW_SPI u8g2(U8G2_R0, /* cs=*/ 10, /* dc=*/ 9, /* reset=*/ 8);  // contrast improved version for ERC12864
//U8G2_ST7565_NHD_C12832_F_4W_SW_SPI u8g2(U8G2_R0, /* clock=*/ 13, /* data=*/ 11, /* cs=*/ 10, /* dc=*/ 9, /* reset=*/ 8);
//U8G2_ST7565_NHD_C12832_F_4W_HW_SPI u8g2(U8G2_R0, /* cs=*/ 10, /* dc=*/ 9, /* reset=*/ 8);
//U8G2_ST7565_NHD_C12864_F_4W_SW_SPI u8g2(U8G2_R0, /* clock=*/ 13, /* data=*/ 11, /* cs=*/ 10, /* dc=*/ 9, /* reset=*/ 8);
//U8G2_ST7565_NHD_C12864_F_4W_HW_SPI u8g2(U8G2_R0, /* cs=*/ 10, /* dc=*/ 9, /* reset=*/ 8);
//U8G2_ST7565_JLX12864_F_4W_SW_SPI u8g2(U8G2_R0, /* clock=*/ 13, /* data=*/ 11, /* cs=*/ 10, /* dc=*/ 9, /* reset=*/ 8);
//U8G2_ST7565_JLX12864_F_4W_HW_SPI u8g2(U8G2_R0, /* cs=*/ 10, /* dc=*/ 9, /* reset=*/ 8);
//U8G2_ST7567_PI_132X64_F_4W_SW_SPI u8g2(U8G2_R0, /* clock=*/ 13, /* data=*/ 11, /* cs=*/ 7, /* dc=*/ 9, /* reset=*/ 8);  // Pax Instruments Shield, LCD_BL=6
//U8G2_ST7567_PI_132X64_F_4W_HW_SPI u8g2(U8G2_R0, /* cs=*/ 7, /* dc=*/ 9, /* reset=*/ 8);  // Pax Instruments Shield, LCD_BL=6
//U8G2_ST7567_JLX12864_F_4W_SW_SPI u8g2(U8G2_R0, /* clock=*/ 13, /* data=*/ 11, /* cs=*/ 7, /* dc=*/ 9, /* reset=*/ 8);  
//U8G2_ST7567_JLX12864_F_4W_HW_SPI u8g2(U8G2_R0, /* cs=*/ 7, /* dc=*/ 9, /* reset=*/ 8);  
//U8G2_ST7567_122X32_F_4W_SW_SPI u8g2(U8G2_R0, /* clock=*/ 13, /* data=*/ 11, /* cs=*/ 7, /* dc=*/ 9, /* reset=*/ 8);  
//U8G2_ST7567_122X32_F_4W_HW_SPI u8g2(U8G2_R0, /* cs=*/ 7, /* dc=*/ 9, /* reset=*/ 8);  
//U8G2_ST7567_OS12864_F_4W_SW_SPI u8g2(U8G2_R0, /* clock=*/ 13, /* data=*/ 11, /* cs=*/ 7, /* dc=*/ 9, /* reset=*/ 8);  
//U8G2_ST7567_OS12864_F_4W_HW_SPI u8g2(U8G2_R0, /* cs=*/ 7, /* dc=*/ 9, /* reset=*/ 8);  
//U8G2_ST7567_ENH_DG128064_F_4W_SW_SPI u8g2(U8G2_R0, /* clock=*/ 13, /* data=*/ 11, /* cs=*/ 10, /* dc=*/ 9, /* reset=*/ 8); 
//U8G2_ST7567_ENH_DG128064_F_4W_HW_SPI u8g2(U8G2_R0, /* cs=*/ 10, /* dc=*/ 9, /* reset=*/ 8); 
//U8G2_ST7567_ENH_DG128064I_F_4W_SW_SPI u8g2(U8G2_R0, /* clock=*/ 13, /* data=*/ 11, /* cs=*/ 10, /* dc=*/ 9, /* reset=*/ 8); 
//U8G2_ST7567_ENH_DG128064I_F_4W_HW_SPI u8g2(U8G2_R0, /* cs=*/ 10, /* dc=*/ 9, /* reset=*/ 8); 
//U8G2_ST7567_64X32_F_HW_I2C u8g2(U8G2_R0, /* reset=*/ U8X8_PIN_NONE); 
//U8G2_ST7567_HEM6432_F_HW_I2C u8g2(U8G2_R0, /* reset=*/ U8X8_PIN_NONE); 
//U8G2_ST7567_ERC13232_F_4W_SW_SPI u8g2(U8G2_R0, /* clock=*/ 13, /* data=*/ 11, /* cs=*/ 10, /* dc=*/ 9, /* reset=*/ 8); 
//U8G2_ST7567_ERC13232_F_4W_HW_SPI u8g2(U8G2_R0, /* cs=*/ 10, /* dc=*/ 9, /* reset=*/ 8); 
//U8G2_ST7567_96X65_F_4W_SW_SPI u8g2(U8G2_R0, /* clock=*/ 13, /* data=*/ 11, /* cs=*/ 10, /* dc=*/ 9, /* reset=*/ 8); 
//U8G2_ST7567_96X65_F_4W_HW_SPI u8g2(U8G2_R0, /* cs=*/ 10, /* dc=*/ 9, /* reset=*/ 8); 
//U8G2_ST7571_128X128_F_4W_SW_SPI u8g2(U8G2_R0, /* clock=*/ 13, /* data=*/ 11, /* cs=*/ 10, /* dc=*/ 9, /* reset=*/ 8);
//U8G2_ST7571_128X128_F_4W_HW_SPI u8g2(U8G2_R0, /* cs=*/ 10, /* dc=*/ 9, /* reset=*/ 8);
//U8G2_ST7571_128X96_F_4W_SW_SPI u8g2(U8G2_R0, /* clock=*/ 13, /* data=*/ 11, /* cs=*/ 10, /* dc=*/ 9, /* reset=*/ 8);
//U8G2_ST7571_128X96_F_4W_HW_SPI u8g2(U8G2_R0, /* cs=*/ 10, /* dc=*/ 9, /* reset=*/ 8);
//U8G2_ST7302_122X250_F_4W_HW_SPI u8g2(U8G2_R0, /* cs=*/ 10, /* dc=*/ 9, /* reset=*/ 8);
//U8G2_ST7586S_JLX384160_F_4W_HW_SPI u8g2(U8G2_R0, /* cs=*/ 10, /* dc=*/ 9, /* reset=*/ 8);
//U8G2_ST7586S_ERC240160_F_4W_HW_SPI u8g2(U8G2_R0, /* cs=*/ 10, /* dc=*/ 9, /* reset=*/ 8);
//U8G2_ST7586S_YMC240160_F_4W_HW_SPI u8g2(U8G2_R0, /* cs=*/ 10, /* dc=*/ 9, /* reset=*/ 8);
//U8G2_ST7586S_JLX320160_F_4W_HW_SPI u8g2(U8G2_R0, /* cs=*/ 10, /* dc=*/ 9, /* reset=*/ 8);             // Uno: Enable U8g2 16 bit mode for this display
//U8G2_ST75160_JM16096_F_4W_SW_SPI u8g2(U8G2_R0, /* clock=*/ 13, /* data=*/ 11, /* cs=*/ 10, /* dc=*/ 9, /* reset=*/ 8);
//U8G2_ST75160_JM16096_F_4W_HW_SPI u8g2(U8G2_R0, /* cs=*/ 10, /* dc=*/ 9, /* reset=*/ 8);
//U8G2_ST75161_JLX160160_F_4W_SW_SPI u8g2(U8G2_R0, /* clock=*/ 13, /* data=*/ 11, /* cs=*/ 10, /* dc=*/ 9, /* reset=*/ 8);
//U8G2_ST75161_JLX160160_F_4W_HW_SPI u8g2(U8G2_R0, /* cs=*/ 10, /* dc=*/ 9, /* reset=*/ 8);
//U8G2_ST75256_JLX172104_F_4W_SW_SPI u8g2(U8G2_R0, /* clock=*/ 13, /* data=*/ 11, /* cs=*/ 10, /* dc=*/ 9, /* reset=*/ 8);
//U8G2_ST75256_JLX172104_F_4W_HW_SPI u8g2(U8G2_R0, /* cs=*/ 10, /* dc=*/ 9, /* reset=*/ 8);
//U8G2_ST75256_JLX19296_F_4W_SW_SPI u8g2(U8G2_R0, /* clock=*/ 13, /* data=*/ 11, /* cs=*/ 10, /* dc=*/ 9, /* reset=*/ 8);
//U8G2_ST75256_JLX19296_F_4W_HW_SPI u8g2(U8G2_R0, /* cs=*/ 10, /* dc=*/ 9, /* reset=*/ 8);
//U8G2_ST75256_JLX16080_F_4W_SW_SPI u8g2(U8G2_R0, /* clock=*/ 13, /* data=*/ 11, /* cs=*/ 10, /* dc=*/ 9, /* reset=*/ 8);
//U8G2_ST75256_JLX16080_F_4W_HW_SPI u8g2(U8G2_R0, /* cs=*/ 10, /* dc=*/ 9, /* reset=*/ 8);
//U8G2_ST75256_JLX256128_F_4W_SW_SPI u8g2(U8G2_R0, /* clock=*/ 13, /* data=*/ 11, /* cs=*/ 10, /* dc=*/ 9, /* reset=*/ 8);	// Enable U8g2 16 bit mode for this display
//U8G2_ST75256_JLX256128_F_4W_HW_SPI u8g2(U8G2_R0, /* cs=*/ 10, /* dc=*/ 9, /* reset=*/ 8);		// Enable U8g2 16 bit mode for this display
//U8G2_ST75256_WO256X128_F_4W_SW_SPI u8g2(U8G2_R0, /* clock=*/ 13, /* data=*/ 11, /* cs=*/ 10, /* dc=*/ 9, /* reset=*/ 8);	// Enable U8g2 16 bit mode for this display
//U8G2_ST75256_WO256X128_F_4W_HW_SPI u8g2(U8G2_R0, /* cs=*/ 10, /* dc=*/ 9, /* reset=*/ 8);		// Enable U8g2 16 bit mode for this display
//U8G2_ST75256_JLX256128_F_4W_SW_SPI u8g2(U8G2_R0, /* clock=*/ 9, /* data=*/ 8, /* cs=*/ 7, /* dc=*/ 6, /* reset=*/ 5);  // MKR Zero, Enable U8g2 16 bit mode for this display
//U8G2_ST75256_JLX256128_F_4W_HW_SPI u8g2(U8G2_R0, /* cs=*/ 7, /* dc=*/ 6, /* reset=*/ 5);  // MKR Zero, Enable U8g2 16 bit mode for this display
//U8G2_ST75256_JLX256160_F_4W_SW_SPI u8g2(U8G2_R0, /* clock=*/ 13, /* data=*/ 11, /* cs=*/ 10, /* dc=*/ 9, /* reset=*/ 8);	// Enable U8g2 16 bit mode for this display
//U8G2_ST75256_JLX256160_F_4W_HW_SPI u8g2(U8G2_R0, /* cs=*/ 10, /* dc=*/ 9, /* reset=*/ 8);		// Enable U8g2 16 bit mode for this display
//U8G2_ST75256_JLX256160M_F_4W_SW_SPI u8g2(U8G2_R0, /* clock=*/ 13, /* data=*/ 11, /* cs=*/ 10, /* dc=*/ 9, /* reset=*/ 8);	// Enable U8g2 16 bit mode for this display
//U8G2_ST75256_JLX256160M_F_4W_HW_SPI u8g2(U8G2_R0, /* cs=*/ 10, /* dc=*/ 9, /* reset=*/ 8);		// Enable U8g2 16 bit mode for this display
//U8G2_ST75256_JLX256160_ALT_F_4W_SW_SPI u8g2(U8G2_R0, /* clock=*/ 13, /* data=*/ 11, /* cs=*/ 10, /* dc=*/ 9, /* reset=*/ 8);	// Enable U8g2 16 bit mode for this display
//U8G2_ST75256_JLX256160_ALT_F_4W_HW_SPI u8g2(U8G2_R0, /* cs=*/ 10, /* dc=*/ 9, /* reset=*/ 8);		// Enable U8g2 16 bit mode for this display
//U8G2_ST75256_JLX240160_F_4W_SW_SPI u8g2(U8G2_R0, /* clock=*/ 13, /* data=*/ 11, /* cs=*/ 10, /* dc=*/ 9, /* reset=*/ 8);
//U8G2_ST75256_JLX240160_F_4W_HW_SPI u8g2(U8G2_R0, /* cs=*/ 10, /* dc=*/ 9, /* reset=*/ 8);
//U8G2_ST75256_JLX25664_F_2ND_HW_I2C u8g2(U8G2_R0, /* reset=*/ 8);	// Due, 2nd I2C, enable U8g2 16 bit mode for this display
//U8G2_ST75320_JLX320240_F_4W_SW_SPI u8g2(U8G2_R0, /* clock=*/ 13, /* data=*/ 11, /* cs=*/ 10, /* dc=*/ 9, /* reset=*/ 8);	// Enable U8g2 16 bit mode for this display
//U8G2_ST75320_JLX320240_F_4W_HW_SPI u8g2(U8G2_R0, /* cs=*/ 10, /* dc=*/ 9, /* reset=*/ 8);		// Enable U8g2 16 bit mode for this display
//U8G2_NT7534_TG12864R_F_4W_SW_SPI u8g2(U8G2_R0, /* clock=*/ 13, /* data=*/ 11, /* cs=*/ 10, /* dc=*/ 9, /* reset=*/ 8);  
//U8G2_NT7534_TG12864R_F_4W_HW_SPI u8g2(U8G2_R0, /* cs=*/ 10, /* dc=*/ 9, /* reset=*/ 8);  
//U8G2_ST7588_JLX12864_F_SW_I2C u8g2(U8G2_R0, /* clock=*/ SCL, /* data=*/ SDA, /* reset=*/ 5);  
//U8G2_ST7588_JLX12864_F_HW_I2C u8g2(U8G2_R0, /* reset=*/ 5);
//U8G2_IST3020_ERC19264_F_6800 u8g2(U8G2_R0, 44, 43, 42, 41, 40, 39, 38, 37,  /*enable=*/ 28, /*cs=*/ 32, /*dc=*/ 30, /*reset=*/ 31); // Connect WR pin with GND
//U8G2_IST3020_ERC19264_F_8080 u8g2(U8G2_R0, 44, 43, 42, 41, 40, 39, 38, 37,  /*enable=*/ 29, /*cs=*/ 32, /*dc=*/ 30, /*reset=*/ 31); // Connect RD pin with 3.3V
//U8G2_IST3020_ERC19264_F_4W_SW_SPI u8g2(U8G2_R0, /* clock=*/ 13, /* data=*/ 11, /* cs=*/ 10, /* dc=*/ 9, /* reset=*/ 8);
//U8G2_IST3088_320X240_F_4W_SW_SPI u8g2(U8G2_R0, /* clock=*/ 13, /* data=*/ 11, /* cs=*/ 10, /* dc=*/ 9, /* reset=*/ 8); 
//U8G2_IST3088_320X240_F_4W_HW_SPI u8g2(U8G2_R0, /* cs=*/ 10, /* dc=*/ 9, /* reset=*/ 8);
//U8G2_IST7920_128X128_F_4W_SW_SPI u8g2(U8G2_R0, /* clock=*/ 13, /* data=*/ 11, /* cs=*/ 10, /* dc=*/ 9, /* reset=*/ 8);  // Round display
//U8G2_IST7920_128X128_F_4W_HW_SPI u8g2(U8G2_R0, /* cs=*/ 10, /* dc=*/ 9, /* reset=*/ 8);  // Round display
//U8G2_LC7981_160X80_F_6800 u8g2(U8G2_R0, 8, 9, 10, 11, 4, 5, 6, 7, /*enable=*/ 18, /*cs=*/ 14, /*dc=*/ 15, /*reset=*/ 16); // Connect RW with GND
//U8G2_LC7981_160X160_F_6800 u8g2(U8G2_R0, 8, 9, 10, 11, 4, 5, 6, 7, /*enable=*/ 18, /*cs=*/ 14, /*dc=*/ 15, /*reset=*/ 16); // Connect RW with GND
//U8G2_LC7981_240X128_F_6800 u8g2(U8G2_R0, 8, 9, 10, 11, 4, 5, 6, 7, /*enable=*/ 18, /*cs=*/ 14, /*dc=*/ 15, /*reset=*/ 16); // Connect RW with GND
//U8G2_LC7981_240X64_F_6800 u8g2(U8G2_R0, 8, 9, 10, 11, 4, 5, 6, 7, /*enable=*/ 18, /*cs=*/ 14, /*dc=*/ 15, /*reset=*/ 16); // Connect RW with GND
//U8G2_LC7981_128X128_F_6800 u8g2(U8G2_R0, 8, 9, 10, 11, 4, 5, 6, 7, /*enable=*/ 18, /*cs=*/ 14, /*dc=*/ 15, /*reset=*/ 16); // Connect RW with GND
//U8G2_SED1520_122X32_F u8g2(U8G2_R0, 8, 9, 10, 11, 4, 5, 6, 7, /*dc=*/ A0, /*e1=*/ A3, /*e2=*/ A2, /* reset=*/  A4); 	// Set R/W to low!
//U8G2_T6963_240X128_F_8080 u8g2(U8G2_R0, 8, 9, 10, 11, 4, 5, 6, 7, /*enable/wr=*/ 17, /*cs/ce=*/ 14, /*dc=*/ 15, /*reset=*/ 16); // Connect RD with +5V, FS0 and FS1 with GND
//U8G2_T6963_256X64_F_8080 u8g2(U8G2_R0, 8, 9, 10, 11, 4, 5, 6, 7, /*enable/wr=*/ 17, /*cs/ce=*/ 14, /*dc=*/ 15, /*reset=*/ 16); // Connect RD with +5V, FS0 and FS1 with GND
//U8G2_T6963_160X80_F_8080 u8g2(U8G2_R0, 8, 9, 10, 11, 4, 5, 6, 7, /*enable/wr=*/ 17, /*cs/ce=*/ 14, /*dc=*/ 15, /*reset=*/ 16); // Connect RD with +5V, FS0 and FS1 with GND
//U8G2_T6963_128X64_F_8080 u8g2(U8G2_R0, 8, 9, 10, 11, 4, 5, 6, 7, /*enable/wr=*/ 17, /*cs/ce=*/ 14, /*dc=*/ 15, /*reset=*/ 16); // Connect RD with +5V, FS0 and FS1 with GND
//U8G2_T6963_128X64_ALT_F_8080 u8g2(U8G2_R0, 8, 9, 10, 11, 4, 5, 6, 7, /*enable/wr=*/ 17, /*cs/ce=*/ 14, /*dc=*/ 15, /*reset=*/ 16); // Connect RD with +5V, FS0 and FS1 with GND
//U8G2_SED1330_240X128_F_8080 u8g2(U8G2_R0, 8, 9, 10, 11, 4, 5, 6, 7, /*enable=*/ 17, /*cs=*/ 14, /*dc=*/ 15, /*reset=*/ 16); // Connect RD with +5V, FG with GND
//U8G2_SED1330_240X128_F_6800 u8g2(U8G2_R0, 13, 11, 2, 3, 4, 5, 6, A4, /*enable=*/ 7, /*cs=*/ 10, /*dc=*/ 9, /*reset=*/ 8); // A0 is dc pin!
//U8G2_SED1330_256X128_F_8080 u8g2(U8G2_R0, 8, 9, 10, 11, 4, 5, 6, 7, /*enable=*/ 17, /*cs=*/ 14, /*dc=*/ 15, /*reset=*/ 16); // Connect /RD = E with +5V, enable is /WR = RW, FG with GND, 14=Uno Pin A0, enable U8g2 16Bit Mode 
//U8G2_SED1330_256X128_F_6800 u8g2(U8G2_R0, 8, 9, 10, 11, 4, 5, 6, 7,  /*enable=*/ 17, /*cs=*/ 14, /*dc=*/ 15, /*reset=*/ 16); // A0 is dc pin, /WR = RW = GND, enable is /RD = E, enable U8g2 16Bit Mode 
//U8G2_SED1330_320X200_F_8080 u8g2(U8G2_R0, 8, 9, 10, 11, 4, 5, 6, 7, /*enable=*/ 17, /*cs=*/ 14, /*dc=*/ 15, /*reset=*/ 16); // Connect /RD = E with +5V, enable is /WR = RW, FG with GND, 14=Uno Pin A0, enable U8g2 16Bit Mode 
//U8G2_SED1330_320X200_F_6800 u8g2(U8G2_R0, 8, 9, 10, 11, 4, 5, 6, 7,  /*enable=*/ 17, /*cs=*/ 14, /*dc=*/ 15, /*reset=*/ 16); // A0 is dc pin, /WR = RW = GND, enable is /RD = E, enable U8g2 16Bit Mode 
//U8G2_RA8835_NHD_240X128_F_8080 u8g2(U8G2_R0, 8, 9, 10, 11, 4, 5, 6, 7, /*enable=*/ 17, /*cs=*/ 14, /*dc=*/ 15, /*reset=*/ 16); // Connect /RD = E with +5V, enable is /WR = RW, FG with GND, 14=Uno Pin A0
//U8G2_RA8835_NHD_240X128_F_6800 u8g2(U8G2_R0, 8, 9, 10, 11, 4, 5, 6, 7,  /*enable=*/ 17, /*cs=*/ 14, /*dc=*/ 15, /*reset=*/ 16); // A0 is dc pin, /WR = RW = GND, enable is /RD = E
//U8G2_UC1601_128X32_F_4W_SW_SPI u8g2(U8G2_R0, /* clock=*/ 13, /* data=*/ 11, /* cs=*/ 10, /* dc=*/ 9, /* reset=*/ 8); 
//U8G2_UC1601_128X64_F_4W_SW_SPI u8g2(U8G2_R0, /* clock=*/ 13, /* data=*/ 11, /* cs=*/ 10, /* dc=*/ 9, /* reset=*/ 8); 
//U8G2_UC1604_JLX19264_F_4W_SW_SPI u8g2(U8G2_R0, /* clock=*/ 13, /* data=*/ 11, /* cs=*/ 10, /* dc=*/ 9, /* reset=*/ 8); 
//U8G2_UC1604_JLX19264_F_4W_HW_SPI u8g2(U8G2_R0, /* cs=*/ 10, /* dc=*/ 9, /* reset=*/ 8);  
//U8G2_UC1609_SLG19264_F_4W_SW_SPI u8g2(U8G2_R0, /* clock=*/ 13, /* data=*/ 11, /* cs=*/ 10, /* dc=*/ 9, /* reset=*/ 8); 
//U8G2_UC1609_SLG19264_F_4W_HW_SPI u8g2(U8G2_R0, /* cs=*/ 10, /* dc=*/ 9, /* reset=*/ 8);  
//U8G2_UC1608_ERC24064_F_4W_SW_SPI u8g2(U8G2_R0, /* clock=*/ 13, /* data=*/ 11, /* cs=*/ 10, /* dc=*/ 9, /* reset=*/ 8);  // SW SPI, Due ERC24064-1 Test Setup
//U8G2_UC1608_DEM240064_F_4W_SW_SPI u8g2(U8G2_R0, /* clock=*/ 13, /* data=*/ 11, /* cs=*/ 10, /* dc=*/ 9, /* reset=*/ 8);  // SW SPI, Due ERC24064-1 Test Setup
//U8G2_UC1608_ERC240120_F_4W_SW_SPI u8g2(U8G2_R0, /* clock=*/ 13, /* data=*/ 11, /* cs=*/ 10, /* dc=*/ 9, /* reset=*/ 8); 
//U8G2_UC1608_240X128_F_4W_SW_SPI u8g2(U8G2_R0, /* clock=*/ 13, /* data=*/ 11, /* cs=*/ 10, /* dc=*/ 9, /* reset=*/ 8);  // SW SPI, Due ERC24064-1 Test Setup
//U8G2_UC1610_EA_DOGXL160_F_4W_SW_SPI u8g2(U8G2_R0, /* clock=*/ 13, /* data=*/ 11, /* cs=*/ 10, /* dc=*/ 9, /* reset=*/  U8X8_PIN_NONE);
//U8G2_UC1610_EA_DOGXL160_F_4W_HW_SPI u8g2(U8G2_R0, /* cs=*/ 10, /* dc=*/ 9, /* reset=*/  U8X8_PIN_NONE);
//U8G2_UC1611_EA_DOGM240_F_2ND_HW_I2C u8g2(U8G2_R0, /* reset=*/ 8);	// Due, 2nd I2C, DOGM240 Test Board
//U8G2_UC1611_EA_DOGM240_F_4W_SW_SPI u8g2(U8G2_R0, /* clock=*/ 13, /* data=*/ 11, /* cs=*/ 10, /* dc=*/ 9, /* reset=*/ 8);   // Due, SW SPI, DOGXL240 Test Board
//U8G2_UC1611_EA_DOGXL240_F_2ND_HW_I2C u8g2(U8G2_R0, /* reset=*/ 8);	// Due, 2nd I2C, DOGXL240 Test Board
//U8G2_UC1611_EA_DOGXL240_F_4W_SW_SPI u8g2(U8G2_R0, /* clock=*/ 13, /* data=*/ 11, /* cs=*/ 10, /* dc=*/ 9, /* reset=*/ 8);   // Due, SW SPI, DOGXL240 Test Board
//U8G2_UC1611_EW50850_F_8080 u8g2(U8G2_R0, 8, 9, 10, 11, 4, 5, 6, 7,  /*enable=*/ 18, /*cs=*/ 3, /*dc=*/ 16, /*reset=*/ 17); // 240x160, Connect RD/WR1 pin with 3.3V, CS is aktive high
//U8G2_UC1611_CG160160_F_8080 u8g2(U8G2_R0, 8, 9, 10, 11, 4, 5, 6, 7,  /*enable=*/ 18, /*cs=*/ 3, /*dc=*/ 16, /*reset=*/ 17); // Connect WR1 and CD1 pin with 3.3V, connect CS0 with cs, WR0 with enable, CD with dc
//U8G2_UC1611_IDS4073_F_4W_SW_SPI u8g2(U8G2_R0, /* clock=*/ 13, /* data=*/ 11, /* cs=*/ 10, /* dc=*/ 9, /* reset=*/ 8);	// Enable U8g2 16Bit Mode 
//U8G2_UC1611_IDS4073_F_4W_HW_SPI u8g2(U8G2_R0, /* cs=*/ 10, /* dc=*/ 9, /* reset=*/ 8);		// Enable U8g2 16Bit Mode 
//U8G2_UC1617_JLX128128_F_4W_SW_SPI u8g2(U8G2_R0, /* clock=*/ 13, /* data=*/ 11, /* cs=*/ 10, /* dc=*/ 9, /* reset=*/ 8);
//U8G2_UC1617_JLX128128_F_4W_HW_SPI u8g2(U8G2_R0, /* cs=*/ 10, /* dc=*/ 9, /* reset=*/ 8);
//U8G2_UC1628_128X64_F_8080 u8g2(U8G2_R0, 8, 9, 10, 11, 4, 5, 6, 7,  /*enable=*/ 18, /*cs=*/ 3, /*dc=*/ 16, /*reset=*/ 17); // UC1628 pin names: enable: /WR, dc: CD
//U8G2_UC1628_128X64_F_4W_SW_SPI u8g2(U8G2_R0, /* clock=*/ 13, /* data=*/ 11, /* cs=*/ 10, /* dc=*/ 9, /* reset=*/ 8);
//U8G2_UC1628_128X64_F_4W_HW_SPI u8g2(U8G2_R0, /* cs=*/ 10, /* dc=*/ 9, /* reset=*/ 8);
//U8G2_UC1628_256X128_F_4W_SW_SPI u8g2(U8G2_R0, /* clock=*/ 13, /* data=*/ 11, /* cs=*/ 10, /* dc=*/ 9, /* reset=*/ 8);
//U8G2_UC1628_256X128_F_4W_HW_SPI u8g2(U8G2_R0, /* cs=*/ 10, /* dc=*/ 9, /* reset=*/ 8);
//U8G2_UC1628_256X32_F_4W_SW_SPI u8g2(U8G2_R0, /* clock=*/ 13, /* data=*/ 11, /* cs=*/ 10, /* dc=*/ 9, /* reset=*/ 8);
//U8G2_UC1628_256X32_F_4W_HW_SPI u8g2(U8G2_R0, /* cs=*/ 10, /* dc=*/ 9, /* reset=*/ 8);
//U8G2_UC1638_192X96_F_4W_SW_SPI u8g2(U8G2_R0, /* clock=*/ 13, /* data=*/ 11, /* cs=*/ 10, /* dc=*/ 9, /* reset=*/ 8);
//U8G2_UC1638_192X96_F_4W_HW_SPI u8g2(U8G2_R0, /* cs=*/ 10, /* dc=*/ 9, /* reset=*/ 8);
//U8G2_UC1638_192X96_F_SW_I2C u8g2(U8G2_R0, /* clock=*/ 13, /* data=*/ 11, /* reset=*/ 8);  // u8g2 test board: I2C clock/data is same as SPI, , I2C default address is 0x78
//U8G2_UC1638_240X128_F_4W_SW_SPI u8g2(U8G2_R0, /* clock=*/ 13, /* data=*/ 11, /* cs=*/ 10, /* dc=*/ 9, /* reset=*/ 8);
//U8G2_UC1638_240X128_F_4W_HW_SPI u8g2(U8G2_R0, /* cs=*/ 10, /* dc=*/ 9, /* reset=*/ 8);
//U8G2_UC1638_240X128_F_SW_I2C u8g2(U8G2_R0, /* clock=*/ 13, /* data=*/ 11, /* reset=*/ 8);  // u8g2 test board: I2C clock/data is same as SPI, , I2C default address is 0x78
//U8G2_SSD1606_172X72_F_4W_SW_SPI u8g2(U8G2_R0, /* clock=*/ 13, /* data=*/ 11, /* cs=*/ 10, /* dc=*/ 9, /* reset=*/ 8);		// eInk/ePaper Display
//U8G2_SSD1607_200X200_F_4W_SW_SPI u8g2(U8G2_R0, /* clock=*/ 13, /* data=*/ 11, /* cs=*/ 10, /* dc=*/ 9, /* reset=*/ 8);	// eInk/ePaper Display, original LUT from embedded artists
//U8G2_SSD1607_GD_200X200_F_4W_SW_SPI u8g2(U8G2_R0, /* clock=*/ 13, /* data=*/ 11, /* cs=*/ 10, /* dc=*/ 9, /* reset=*/ 8);	// Good Display
//U8G2_SSD1607_WS_200X200_F_4W_SW_SPI u8g2(U8G2_R0, /* clock=*/ 13, /* data=*/ 11, /* cs=*/ 10, /* dc=*/ 9, /* reset=*/ 8);	// Waveshare
//U8G2_IL3820_296X128_F_4W_SW_SPI u8g2(U8G2_R0, /* clock=*/ 13, /* data=*/ 11, /* cs=*/ 10, /* dc=*/ 9, /* reset=*/ 8);	// WaveShare 2.9 inch eInk/ePaper Display, enable 16 bit mode for this display!
//U8G2_IL3820_V2_296X128_F_4W_SW_SPI u8g2(U8G2_R0, /* clock=*/ 13, /* data=*/ 11, /* cs=*/ 10, /* dc=*/ 9, /* reset=*/ 8);	// ePaper Display, lesser flickering and faster speed, enable 16 bit mode for this display!
//U8G2_MAX7219_64X8_F_4W_SW_SPI u8g2(U8G2_R0, /* clock=*/ 11, /* data=*/ 12, /* cs=*/ 10, /* dc=*/ U8X8_PIN_NONE, /* reset=*/ U8X8_PIN_NONE);
//U8G2_MAX7219_32X8_F_4W_SW_SPI u8g2(U8G2_R0, /* clock=*/ 11, /* data=*/ 12, /* cs=*/ 10, /* dc=*/ U8X8_PIN_NONE, /* reset=*/ U8X8_PIN_NONE);
//U8G2_MAX7219_8X8_F_4W_SW_SPI u8g2(U8G2_R0, /* clock=*/ 11, /* data=*/ 12, /* cs=*/ 10, /* dc=*/ U8X8_PIN_NONE, /* reset=*/ U8X8_PIN_NONE);
//U8G2_LS013B7DH03_128X128_F_4W_HW_SPI u8g2(U8G2_R0, /* cs=*/ 10, /* dc=*/ U8X8_PIN_NONE, /* reset=*/ 8);	// there is no DC line for this display
//U8G2_LS027B7DH01_400X240_F_4W_HW_SPI u8g2(U8G2_R0, /* cs=*/ 10, /* dc=*/ U8X8_PIN_NONE, /* reset=*/ 8);	// there is no DC line for this display, SPI Mode 2
//U8G2_LS027B7DH01_M0_400X240_F_4W_HW_SPI u8g2(U8G2_R0, /* cs=*/ 10, /* dc=*/ U8X8_PIN_NONE, /* reset=*/ 8);	// there is no DC line for this display, SPI Mode 0
//U8G2_LS013B7DH05_144X168_F_4W_HW_SPI u8g2(U8G2_R0, /* cs=*/ 10, /* dc=*/ U8X8_PIN_NONE, /* reset=*/ 8);	// there is no DC line for this display
//U8G2_ST7511_AVD_320X240_F_8080 u8g2(U8G2_R0, 13, 11, 2, 3, 4, 5, 6, A4, /*enable/WR=*/ 7, /*cs=*/ 10, /*dc=*/ 9, /*reset=*/ 8); // Enable U8g2 16Bit Mode and connect RD pin with 3.3V/5V
//U8G2_S1D15300_LM6023_F_4W_SW_SPI u8g2(U8G2_R0, /* clock=*/ 13, /* data=*/ 11, /* cs=*/ 10, /* dc=*/ 9, /* reset=*/ 8);
//U8G2_S1D15300_LM6023_F_4W_HW_SPI u8g2(U8G2_R0, /* cs=*/ 10, /* dc=*/ 9, /* reset=*/ 8);
//U8G2_S1D15300_100X32_F_4W_SW_SPI u8g2(U8G2_R0, /* clock=*/ 13, /* data=*/ 11, /* cs=*/ 10, /* dc=*/ 9, /* reset=*/ 8);
//U8G2_S1D15300_100X32_F_4W_HW_SPI u8g2(U8G2_R0, /* cs=*/ 10, /* dc=*/ 9, /* reset=*/ 8);
//U8G2_S1D15300_100X32I_F_4W_SW_SPI u8g2(U8G2_R0, /* clock=*/ 13, /* data=*/ 11, /* cs=*/ 10, /* dc=*/ 9, /* reset=*/ 8);
//U8G2_S1D15300_100X32I_F_4W_HW_SPI u8g2(U8G2_R0, /* cs=*/ 10, /* dc=*/ 9, /* reset=*/ 8);
//U8G2_S1D15721_240X64_F_4W_SW_SPI u8g2(U8G2_R0, /* clock=*/ 13, /* data=*/ 11, /* cs=*/ 10, /* dc=*/ 9, /* reset=*/ 8);
//U8G2_S1D15721_240X64_F_4W_HW_SPI u8g2(U8G2_R0, /* cs=*/ 10, /* dc=*/ 9, /* reset=*/ 8);
//U8G2_GU800_128X64_F_4W_SW_SPI u8g2(U8G2_R0, /* clock=*/ 13, /* data=*/ 11, /* cs=*/ 10, /* dc=*/ 9, /* reset=*/ 8);
//U8G2_GU800_128X64_F_4W_HW_SPI u8g2(U8G2_R0, /* cs=*/ 10, /* dc=*/ 9, /* reset=*/ 8);
//U8G2_GU800_160X16_F_4W_SW_SPI u8g2(U8G2_R0, /* clock=*/ 13, /* data=*/ 11, /* cs=*/ 10, /* dc=*/ 9, /* reset=*/ 8);
//U8G2_GU800_160X16_F_4W_HW_SPI u8g2(U8G2_R0, /* cs=*/ 10, /* dc=*/ 9, /* reset=*/ 8);
//U8G2_GP1294AI_256X48_F_4W_HW_SPI u8g2(U8G2_R0, /* cs=*/10, /* dc=*/U8X8_PIN_NONE, /* reset=*/8);

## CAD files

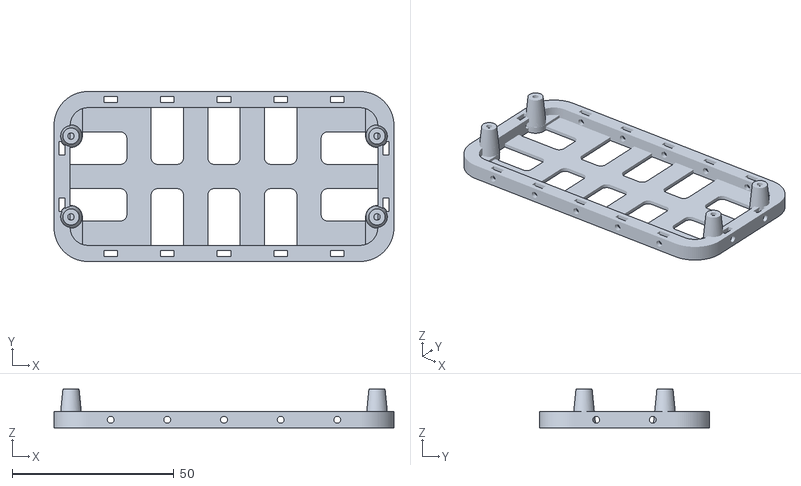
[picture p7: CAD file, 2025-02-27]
3D-Print/modular_case_18650_charger.stl
105.0 x 52.5 x 12.0

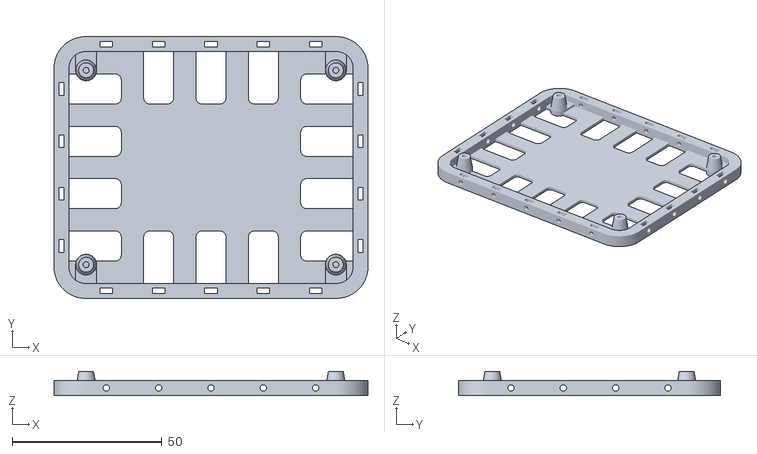
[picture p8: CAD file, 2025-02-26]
3D-Print/modular_case_euro_big.stl
105.0 x 87.5 x 8.05

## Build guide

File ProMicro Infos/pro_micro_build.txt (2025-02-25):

https://web.archive.org/web/20240706045800/https://forum.sparkfun.com/viewtopic.php?f=96&t=53770

------------------------------------------------------------------------------------------------------------------------

Hi All,

I recently bought some Pro Micros for the first time. (Fantastic! For software testing I needed to enter lots of data into a target computer that is in a VM and 2 remote desktop jumps from my PC. The Pro Micro did the job. Rather strange running a program on my PC talking serial to Pro Micro, sending mouse+keys back up the same wire to the same computer.)

It may have been my computer, but the Arduino IDE usually failed to load the Pro Micro. The automatic way failed, and I could never press the reset at the right time. So I looked at using a bat file and it works perfectly, 99/100 instead of 1/10. (The tutorial part about reloading the boot program says only 8 seconds to do something. I haven't needed this yet but it's probably easier with a bat file.)

Save the code below as e.g. Pro_Micro_Build.bat in a normal Arduino sketch directory. It gets the directory and filenames automatically. You have to check and maybe edit four things: board-type, com port, Arduino location, Avrdude location. It compiles the sketch, prompts you to reset the Pro Micro, then uses mode and find to wait for the port to appear. (Clunky but it works.) It uses Avrdude to load the board. (Command lifted from IDE console.) It’s slightly faster if you hold the reset and let go when prompted to reset.

I've seen a few posts about difficulties loading the Pro Micro so I hope this helps.

Richard.

------------------------------------------------------------------------------------------------------------------------

Hallo zusammen,

Ich habe kürzlich zum ersten Mal ein paar Pro -Micros gekauft. (Fantastisch! Für Softwaretests musste ich viele Daten in einen Zielcomputer eingeben, der sich in einem VM- und 2 Remote -Desktop -Sprüngen von meinem PC befindet. Der Pro Micro hat den Job gemacht. Ziemlich seltsame Ausführung eines Programms auf meinem PC, der seriell mit Pro spricht zu Pro Micro, Senden von Maus+Tasten denselben Kabel auf denselben Computer.)

Es mag mein Computer gewesen sein, aber die Arduino -IDE konnte das Pro -Mikro normalerweise nicht laden. Der automatische Weg scheiterte und ich konnte den Reset niemals zum richtigen Zeitpunkt drücken. Also habe ich mich mit einer Fledermausdatei angesehen und sie funktioniert perfekt, 99/100 anstelle von 1/10. (Der Tutorial -Teil über das Neuladen des Boot -Programms sagt nur 8 Sekunden an, um etwas zu tun. Ich habe dies noch nicht gebraucht, aber es ist wahrscheinlich einfacher mit einer Fledermausdatei.)

Speichern Sie den folgenden Code als EG pro_micro_build.bat in einem normalen Arduino -Skizzenverzeichnis. Es erhält das Verzeichnis und die Dateinamen automatisch. Sie müssen vier Dinge überprüfen und bearbeiten: Board-Typ, COM-Port, Arduino-Standort, Avrdude-Standort. Es kompiliert die Skizze, fordert Sie auf, das Pro Micro zurückzusetzen, und verwendet den Modus und findet, um zu warten, bis der Port angezeigt wird. (Klobig, aber es funktioniert.) Es verwendet AvrDude, um das Board zu laden. (Befehl, der von der IDE -Konsole aufgehoben wurde.) Wenn Sie den Reset halten und loslassen, wenn Sie zum Zurücksetzen aufgefordert werden.

Ich habe ein paar Beiträge über Schwierigkeiten gesehen, das Pro Micro zu laden, also hoffe ich, dass dies hilft.

Richard.

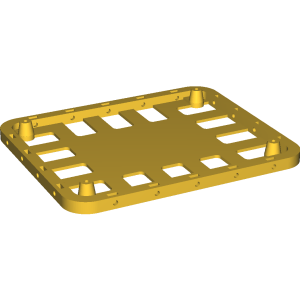
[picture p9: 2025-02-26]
3D-Print/modular_case_euro_big.png

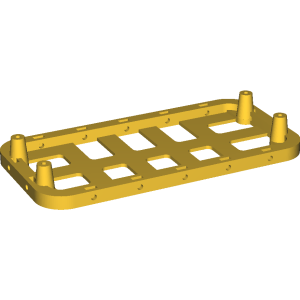
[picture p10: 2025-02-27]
3D-Print/modular_case_18650_charger.png

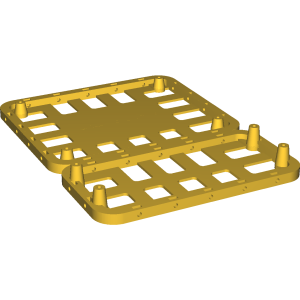
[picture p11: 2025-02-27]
3D-Print/modular_case_euro_big_18650_charger.png

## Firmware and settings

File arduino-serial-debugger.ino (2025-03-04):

////////////////////////////////////////////////////////////////////////////////////
//  Serial Port Debugger/Monitor 
//  https://github.com/ma-ha/arduino-serial-debugger
//  by ma-ha 
//  Copyright (c) 2023 ma-ha, MIT License
//  --------------------------------------------------------------------------------
//  Adapted by Franziska Walter
//  2025/02 
//  https://github.com/FranziHH/arduino-serial-debugger
////////////////////////////////////////////////////////////////////////////////////

#include <Arduino.h>
#include <U8g2lib.h>

#define DISPLAY_TXT 'T'
#define DISPLAY_HEX 'H'
#define DISPLAY_BIN 'B'

/* Print Serial Input to Serial Console 
 * ! only when second hardware serial available !
 */
#define DEBUG
/* print Button Actions */
#define DEBUG_MSG

// include config
#include "config.h"

#if defined(__AVR__)
  #include "PinChangeInterrupt.h"

  #if defined(__AVR_ATmega328P__) || defined(__AVR_ATmega168__)
    //Code in here will only be compiled if an Arduino Uno (or older) is used.
    #if defined(DEBUG) || defined(DEBUG_MSG)
      #undef DEBUG
      #undef DEBUG_MSG
      #warning Disable Debug - Only one Serial available!
    #endif

    #define mySerial Serial
    #define RECOGNIZED
  #endif
  
  #if defined(__AVR_ATmega32U4__) || defined(__AVR_ATmega16U4__)
    //Code in here will only be compiled if an Arduino Leonardo is used.
    #define mySerial Serial1
    #define RECOGNIZED
  #endif
#endif

// ============================================================================

#if defined(ESP8266)
  #define ISR_ATTR ICACHE_RAM_ATTR

  #if defined(DEBUG) || defined(DEBUG_MSG)
    #undef DEBUG
    #undef DEBUG_MSG
    #warning Disable Debug - Only one Serial available!
  #endif

  #define mySerial Serial
  #define RECOGNIZED
#endif

// ============================================================================

#if defined(ESP32)
  #define ISR_ATTR IRAM_ATTR

  #include <HardwareSerial.h>
  HardwareSerial mySerial(2);
  #define RECOGNIZED
#endif

// ============================================================================

#ifndef RECOGNIZED
  #error Board was not recognized
#endif

#ifndef ISR_ATTR
  #define ISR_ATTR 
#endif

#if defined(DEBUG_MSG) && !defined(DEBUG) 
  #define DEBUG
#endif

#ifdef U8X8_HAVE_HW_SPI
  #include <SPI.h>
#endif
#ifdef U8X8_HAVE_HW_I2C
  #include <Wire.h>
#endif

unsigned long baud = BAUD_DEFAULT_0;
char mode = DISPLAY_DEFAULT_0;

String str[8];
String tmp;
boolean isStartScreen = true;
boolean changed = false;
boolean changedMode = false;
boolean changedBaud = false;
boolean changedScreen = false;
byte strLen = 0;
byte inputMode = 0;
byte lastInputMode = 0;
byte debounceTime = 100;
unsigned long lastTime[4];

// ============================================================================

void readInputSwitch() {
  inputMode = 0;
  #if defined(INP_PIN_1)
    if (digitalRead(INP_PIN_1) == LOW) {
      inputMode = 1;
    }
  #endif
  #if defined(INP_PIN_2)
    if (digitalRead(INP_PIN_2) == LOW) {
      inputMode = 2;
    }
  #endif
  if (inputMode != lastInputMode) {
    switch (inputMode) {
      #if defined(INP_PIN_1)
      case 1: baud = BAUD_DEFAULT_1; mode = DISPLAY_DEFAULT_1; break;
      #endif
      #if defined(INP_PIN_2)
      case 2: baud = BAUD_DEFAULT_2; mode = DISPLAY_DEFAULT_2; break;
      #endif
      default: baud = BAUD_DEFAULT_0; mode = DISPLAY_DEFAULT_0; break;
    }
    // clear screen
    if (!isStartScreen) for (byte i = 0; i < 8; i++) str[i] = "";
    changedBaud = true;
    changedMode = true;
    lastInputMode = inputMode;
    changed = true; // is double ..
  }
}

// ============================================================================

void loop(void) {
  readInputSwitch();

  if (changedBaud) {
    mySerial.end(); 
    mySerial.begin(baud); 
    changedBaud = false;
    changed = true;
    #if defined(DEBUG_MSG)
      Serial.print("Baud ");
      Serial.println(baud);
    #endif
  }
  if (changedMode) {
    changedMode = false;
    changed = true;
    #if defined(DEBUG_MSG)
      Serial.print("Mode ");
      Serial.println(mode);
    #endif
  }
  if (changedScreen) {
    changedScreen = false;
    changed = true;
    #if defined(DEBUG_MSG)
      Serial.println("Clear Screen");
    #endif
  }
  readStr();
  if (changed) {
    writeOLED();
    changed = false;
  }
}

// ============================================================================

void writeOLED() {
  u8g2.clearBuffer(); 
  u8g2.setFont( u8g2_font_5x7_tf ); 
  for ( byte i=0; i < 8; i++ ) {
    u8g2.drawStr( 0, 64-7*i, str[i].c_str() );  
  }
  u8g2.setFont( u8g2_font_tinytim_tf ); 
  u8g2.drawStr( 95, 5, String( baud ).c_str()  );
  switch (mode) {
    case DISPLAY_TXT: u8g2.drawStr( 85, 5, "T" ); break;
    case DISPLAY_BIN: u8g2.drawStr( 85, 5, "B" ); break;
    case DISPLAY_HEX: u8g2.drawStr( 85, 5, "H" ); break;
    default: u8g2.drawStr( 85, 5, "t" ); break;
  }
  switch (inputMode) {
    #if defined(INP_PIN_1)
    case 1: u8g2.drawStr( 0, 5, INP_TXT_1 ); break;
    #endif
    #if defined(INP_PIN_2)
    case 2: u8g2.drawStr( 0, 5, INP_TXT_2 ); break;
    #endif
    default: u8g2.drawStr( 0, 5, INP_TXT_0 ); break;
  }
  u8g2.sendBuffer();    
}

// ============================================================================

void readStr() {
  while ( mySerial.available() > 0 ) {
    char inChar = (char) mySerial.read();
    
    switch (mode) {
      case DISPLAY_TXT: 
        strLen ++;
        if ( inChar == '\n' ) {
          newLine();
        } else if ( strLen > 23 ) {
          newLine();
          str[0] += inChar;
        } else {
          str[0] += inChar;
        }
        break;
      case DISPLAY_BIN: 
        if ( strLen > 2 ) {
          newLine();
        }
        str[0] += String( inChar, BIN ) + " ";
        strLen ++;
        break;
      case DISPLAY_HEX: 
        strLen += 3;
        tmp = String( inChar, HEX );
        if ( tmp.length() < 2 ) {
          str[0] += "0" + tmp + " ";
        } else if ( tmp.length() > 2 ) {
          // wrong char
          str[0] += "xx ";
        } else {
          str[0] += tmp + " ";
        }
        if ( strLen > 23 ) {
          newLine();
        }
        break;
      default: break;
    }

    if (isStartScreen && ((millis() - lastTime[0]) > 1000)) {
      for (byte i = 1; i < 8; i++) str[i] = "";
      isStartScreen = false;
    }

    changed = true;
  }
}

// ============================================================================

void newLine() {
  #if defined(DEBUG)
    Serial.println( str[0].c_str() );
  #endif
  for ( byte i = 7; i > 0; i-- ) {
    str[i] = str[i-1];
  }
  str[0] = "";
  strLen = 0;
}

// ============================================================================

void ISR_ATTR changeBaud() {
  if ((millis() - lastTime[1]) > debounceTime) {
    lastTime[1] = millis();
    if (baud == 1200) {
      baud =  2400;
    } else if (baud == 2400 ) {
      baud =  4800;
    } else if (baud == 4800 ) {
      baud =  9600;
    } else if (baud == 9600 ) {
      baud =  19200;
    } else if (baud ==  19200 ) {
      baud =  38400;
    } else if (baud ==  38400 ) {
      baud =  57600;
    } else if (baud ==  57600 ) {
      baud =  115200;
    } else if (baud == 115200 ) {
      baud = 230400;
    } else if (baud == 230400 ) {
      baud = 1200;
    }
    changedBaud = true;
  }
}

// ============================================================================

void ISR_ATTR changeMode() {
  if ((millis() - lastTime[2]) > debounceTime) {
    lastTime[2] = millis();
    if (mode == DISPLAY_TXT) {
      mode = DISPLAY_HEX;
    } else if (mode == DISPLAY_HEX) {
      mode = DISPLAY_BIN;    
    } else if (mode == DISPLAY_BIN) {
      mode = DISPLAY_TXT;
    }
    changedMode = true;
  }
}

// ============================================================================

void ISR_ATTR clearScreen() {
  if ((millis() - lastTime[3]) > debounceTime) {
    lastTime[3] = millis();
    for (byte i = 0; i < 8; i++) {
      str[i] = "";
    }
    strLen = 0;
    changedScreen = true;
  }
}

// ============================================================================

void setup(void) {
  #if defined(DEBUG)
    Serial.begin(9600); 
  #endif
  mySerial.begin(baud); 
  u8g2.begin();

  for ( byte i = 0; i < 8; i++ ) {
    str[i].reserve(25);
    str[i] = "";
  }
  str[6] = "  SERIAL PORT DEBUGGER V4";
  str[5] = "            BY";
  str[4] = "      MAKER GARAGE DE";
  str[3] = "  ----------------------";
  str[2] = "    2025/03 ADAPTED BY";
  str[1] = "      FRANZI.HAMBURG";
  str[0] = "";

  #if defined(DEBUG)
    Serial.println("SERIAL PORT DEBUGGER v4");
  #endif

  // button config
  pinMode(BAUD_PIN, INPUT_PULLUP);
  pinMode(MODE_PIN, INPUT_PULLUP);
  pinMode(CLS_PIN, INPUT_PULLUP);
  #if defined(INP_PIN_1)
    pinMode(INP_PIN_1, INPUT_PULLUP);
  #endif
  #if defined(INP_PIN_2)
    pinMode(INP_PIN_2, INPUT_PULLUP);
  #endif

#if defined(__AVR__)
  attachPinChangeInterrupt( 
    digitalPinToPinChangeInterrupt(BAUD_PIN), 
    changeBaud, 
    RISING 
  );
  attachPinChangeInterrupt( 
    digitalPinToPinChangeInterrupt(MODE_PIN), 
    changeMode, 
    RISING   
  );
  attachPinChangeInterrupt( 
    digitalPinToPinChangeInterrupt(CLS_PIN), 
    clearScreen, 
    RISING   
  );
// #elif defined(ESP32) || defined(ESP8266)
#else
  attachInterrupt(BAUD_PIN, changeBaud, RISING);
  attachInterrupt(MODE_PIN, changeMode, RISING);
  attachInterrupt(CLS_PIN, clearScreen, RISING);
#endif

  readInputSwitch();
  writeOLED();
  lastTime[0] = millis();

}

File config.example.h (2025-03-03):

/**********************************************************************

The configuration file for Serial Debugger

rename / or copy this File to config.h

**********************************************************************/

#if defined(__AVR__)
  #if defined(__AVR_ATmega328P__) || defined(__AVR_ATmega168__)
    // UNO, Nano

    // I2C: SDA - A4, SCL - A5
    // Serial: RX - 1, TX - 0

    // Buttons PIN
    #define BAUD_PIN 10
    #define MODE_PIN 11
    #define CLS_PIN  12

    // Define Display: Display Defines, see U8g2 Contructor List.txt
    U8G2_SH1106_128X64_NONAME_F_HW_I2C u8g2(U8G2_R0, /* reset=*/ U8X8_PIN_NONE);
  #endif
  
  #if defined(__AVR_ATmega32U4__) || defined(__AVR_ATmega16U4__)
    // Leonardo, Micro

    // I2C: SDA - 2, SCL - 3
    // Serial: RX - 1, TX - 0

    // Buttons PIN
    #define BAUD_PIN 10
    #define MODE_PIN 9
    #define CLS_PIN  16

    // Define Display: Display Defines, see U8g2 Contructor List.txt
    U8G2_SH1106_128X64_NONAME_F_HW_I2C u8g2(U8G2_R0, /* reset=*/ U8X8_PIN_NONE);
  #endif
#endif

#if defined(ESP8266)
  // ESP8266 Boards

  // I2C: SDA - D2 (GPIO4), SCL - D1 (GPIO5)
  // Serial: RX - GPIO3, TX - GPIO1

    // Buttons PIN
    #define BAUD_PIN D5
    #define MODE_PIN D6
    #define CLS_PIN  D7

    // Define Display: Display Defines, see U8g2 Contructor List.txt
    U8G2_SH1106_128X64_NONAME_F_HW_I2C u8g2(U8G2_R0, /* reset=*/ U8X8_PIN_NONE);
#endif

#if defined(ESP32)
  // ESP32 Boards

  // I2C: SDA - 21, SCL - 22
  // Serial: RX - 16, TX - 17

  // Buttons PIN
  #define BAUD_PIN 27
  #define MODE_PIN 26
  #define CLS_PIN  25

  /* 
    INPUT_PIN_X is optional !
    if INPUT_PIN_X is defined, 
    the other definitions must also be defined
  */
  // input switch
  #define INP_PIN_1 18
  #define INP_TXT_1 "RS232 WLESS"
  #define DISPLAY_DEFAULT_1 DISPLAY_TXT
  #define BAUD_DEFAULT_1 115200

  #define INP_PIN_2 19
  #define INP_TXT_2 "RS485"
  #define DISPLAY_DEFAULT_2 DISPLAY_HEX
  #define BAUD_DEFAULT_2 9600

  // Define Display: Display Defines, see U8g2 Contructor List.txt
  U8G2_SSD1306_128X64_NONAME_F_HW_I2C u8g2(U8G2_R0, /* reset=*/ U8X8_PIN_NONE);
#endif

// Defaults at Start
#define INP_TXT_0 "RS232"
// DISPLAY_TXT / DISPLAY_HEX / DISPLAY_BIN
#define DISPLAY_DEFAULT_0 DISPLAY_HEX
// 1200 / 2400 / 4800 / 9600 / 19200 / 38400 / 57500 / 115200 / 230400
#define BAUD_DEFAULT_0 19200

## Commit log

2025-02-26 - Boards Arduino Nano and Uno added: Here debugging is disabled, there is only a hardware serial interface - The display definition has been moved to config.h. Individual settings are possible here.
2025-02-26 added 3D Print Files for PCB Holder
    [modular_case_18650_charger.stl, modular_case_euro_big.stl]
2025-02-26 Code cleaned and compressed, bugs fixed
    [arduino-serial-debugger.ino, config.example.h]
2025-02-27 Fixed errors in 3D printing files
    [modular_case_18650_charger.stl]
2025-03-03 Added the option to switch between a maximum of 3 inputs: - default (always RS232) - Input1 (e.g. HC12 radio module) - Input2 (e.g. RS485) Added The selected input is shown in the display When switch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
2025-03-03 Update README.md - Images with Input wireless and RS485
2025-03-04 debounce mode buttons (100 ms) nonblocking start screen
